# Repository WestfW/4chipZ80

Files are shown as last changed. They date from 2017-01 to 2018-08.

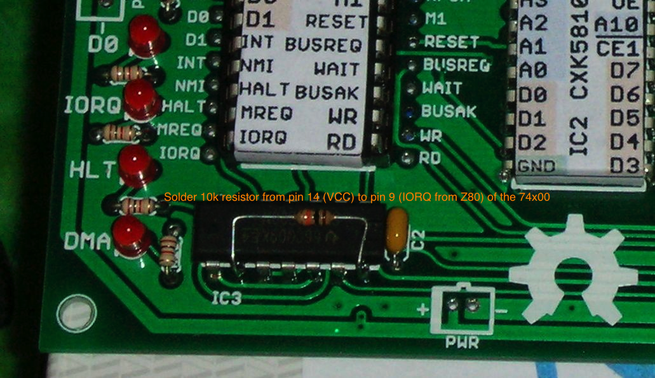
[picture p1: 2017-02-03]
Gerbers-V1bad/Fix-2-IORQ-PullUp.jpg

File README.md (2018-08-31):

# 4chipZ80
Z80 system using ATmega as IO/boot controller.  4 chips total.
---
This is a minimalist Z80 system based on a breadboard design by "Just4Fun" at hackaday.io:
https://hackaday.io/project/19000

My main contribution so far is the creation of a PCB, for a more permenant construction than the original breadboard.
This involved converting the printed schematic to an EAGLE version, as well as laying out the PCB. 

This project has won an **"Anything Goes" HackaDay prize** (for Just4Fun), and at this point has been built by a relatively impressive number of people in a rather impressive variety of different ways (not all of them using this PCB.)

The initial V1 PCB was sent for fabrication at PCBWAY.COM on 20170111.  It's been received, reviewed, and built (fully built as of 20170202), and it works, but it has some bugs:

 1. Short of I2C line to Ground plain.
 2. Missing pullup (IORQ) and pulldown (RESET) resistors.
 3. Rx/Tx swapped on serial connection.
 
Fixing these manually results in a working board.  It's not clear that the pull-resistors are needed.

There are now several versions of the EAGLE Schematic/PCB design posted here:

 1. Gerbers-v1bad.Z80-4chip-PCBWAY-BAD.\* - the design as sent to PCBWAY, complete with errors (except that the errors are "marked.")
With hand-done re-work, this design is known to work.  See the notes in the "To-Do" layer of the board, and the assorted "fix\*" files in that directory.
 1. Z80-4chip-v2.1.\* is the "corrected" design.  It has the fixes for the known bugs.  It also features a clarified (multi-sheet) schematic, *BUT* I have not personally fabbed or tested it, but several people on Hackaday.io have built V2 boards and say that they work.
 2. Z80-4chip-v3.\* Adds sockets for I2C EEPROM "Floppy Disks" that should permit use of CP/M and perhaps other Operating Systems.  Just4Fun has implemented the CP/M and QP/M BIOS and etc.  This has also not yet been fabbed or tested (but I have a volunteer!)  (Also Gerbers-V3/\* has pre-made geber files.)

I don't know if I'll be sending the "new" design(s) to actually be built.  A guy can only use so many Z80 boards, and I'm not up for being "in business."  I'll try to keep this update if other people use the design successfully.

Potential users may want to note that the original developer of the 4-chip Z80 system (Just4Fun) has published a new and improved version of the design that includes a PCB, at https://hackaday.io/project/159973

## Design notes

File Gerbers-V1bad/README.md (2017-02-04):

# Gerbers-V1bad

This has Gerber and Design files for the fabbed board that has know bugs
(but can be made to work.  See photos and .BRD file for detailed (?)
descriptions of the errors (look on the TODO and HISTORY layers.)

 1. SCL shorted to bottom-side ground trace.
 2. RX and TX on FTDI connector swapped.
 3. Missing pullup on IORQ  (may not be required)
 4. Missing pulldown on RESET  (may not be required)

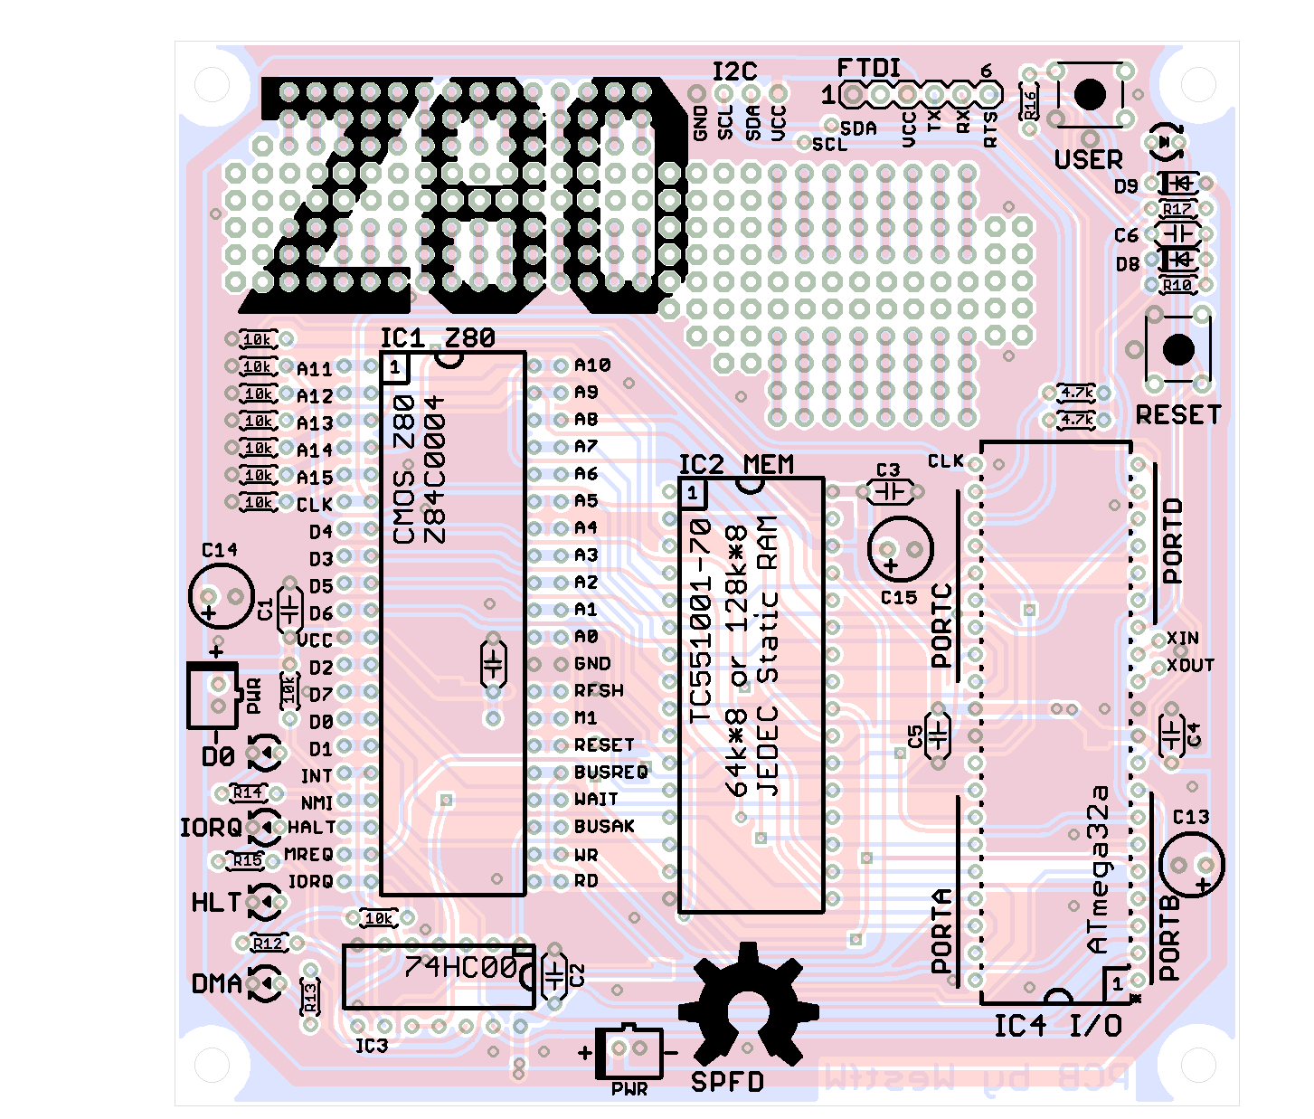
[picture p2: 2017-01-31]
z80.png

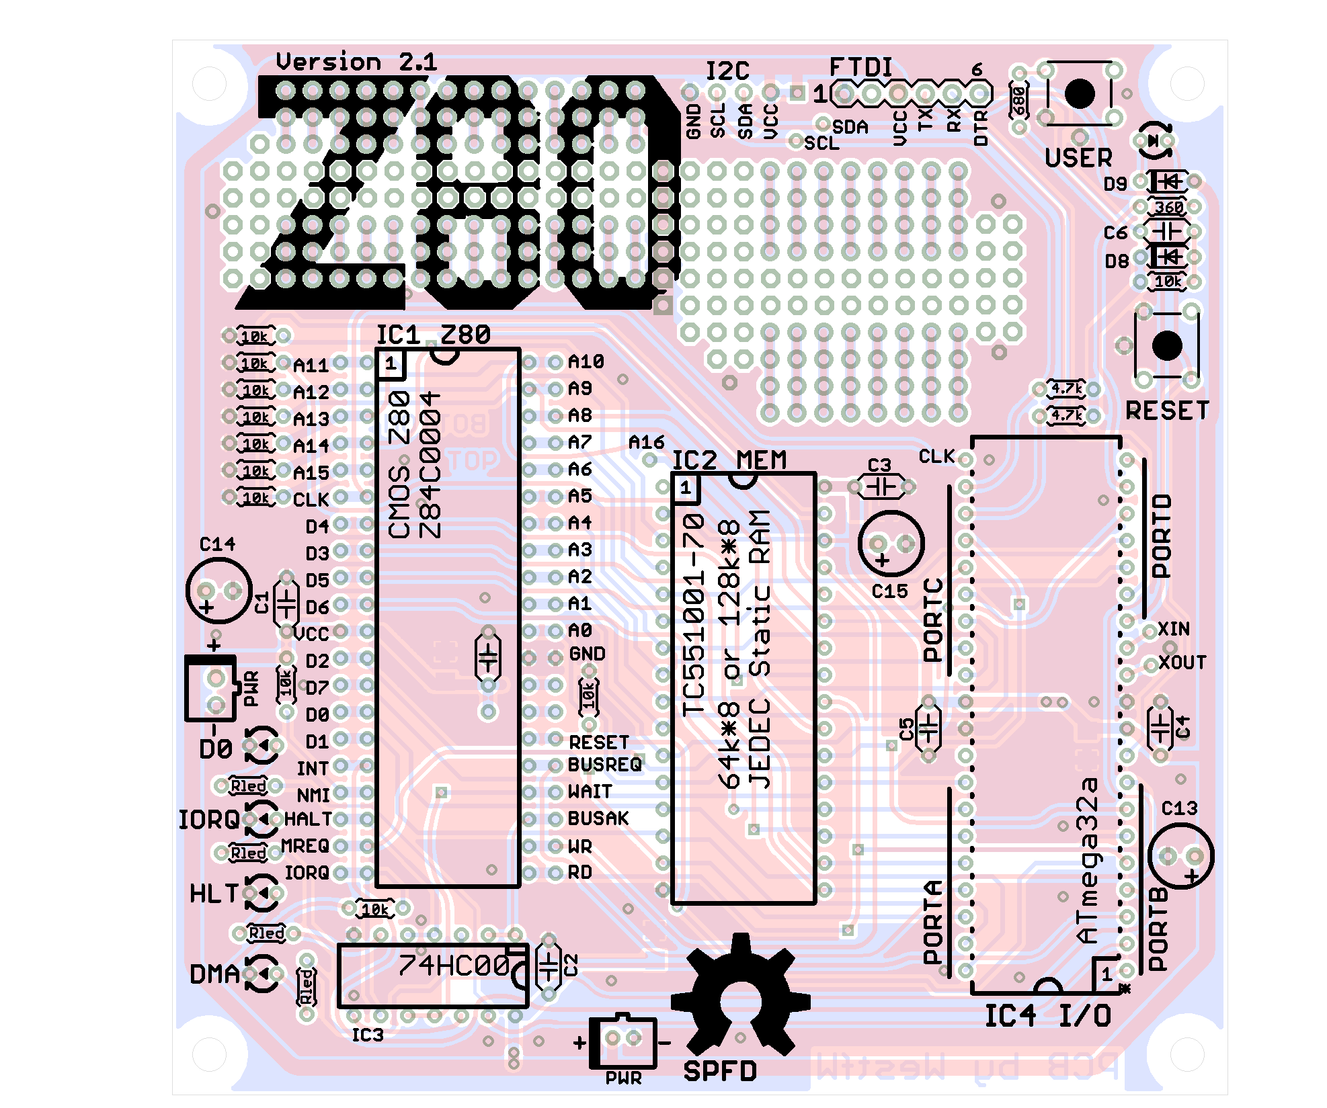
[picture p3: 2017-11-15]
Z80-4chip-v2.1.png

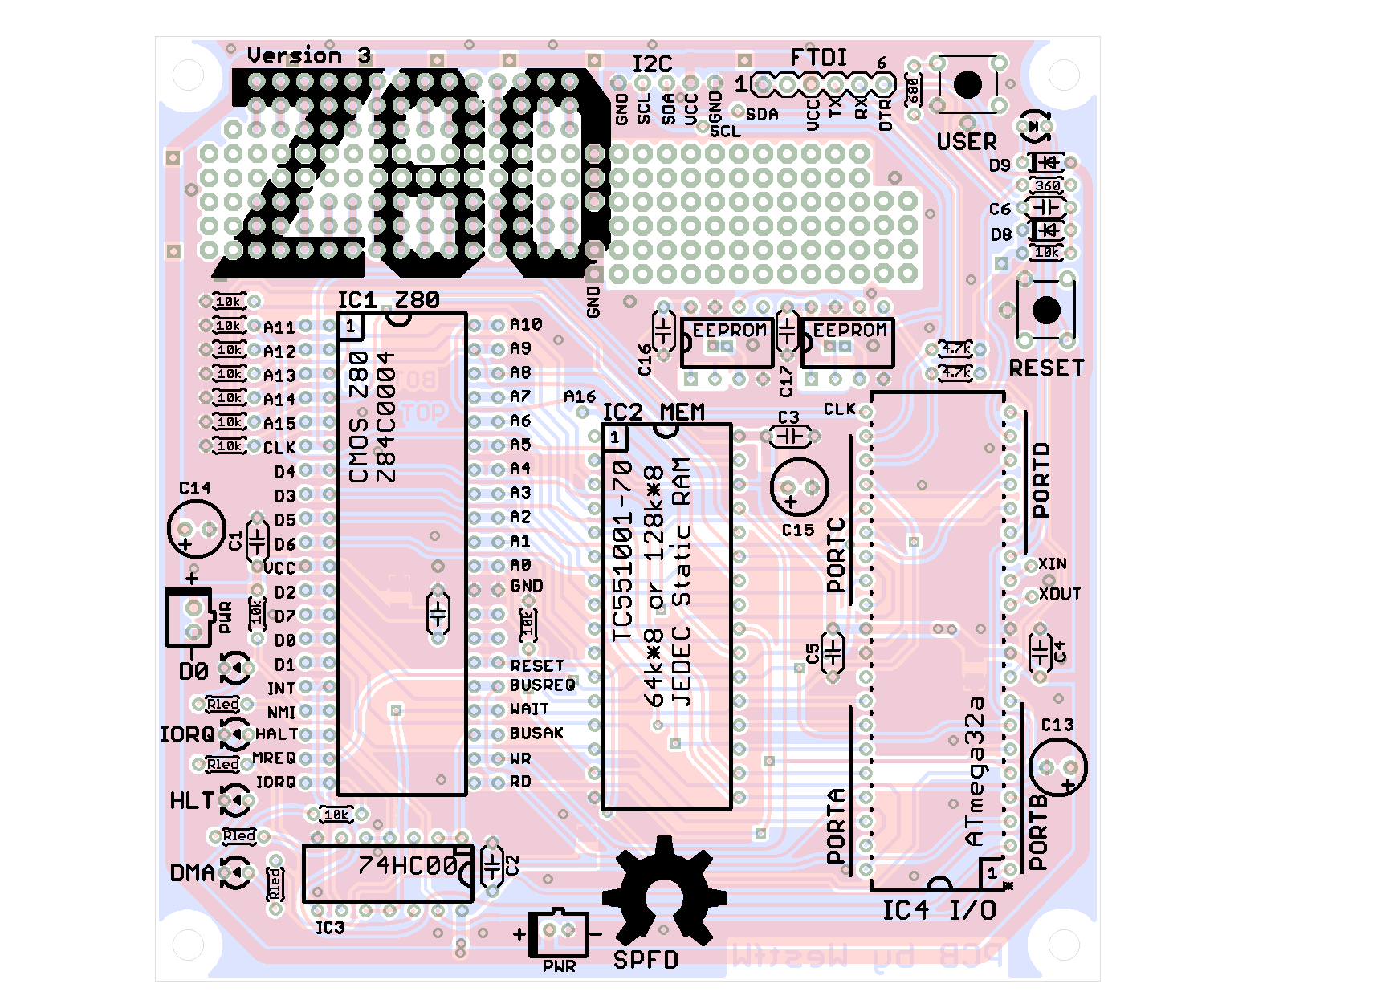
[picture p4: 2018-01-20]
Z80-4chip-v3.png

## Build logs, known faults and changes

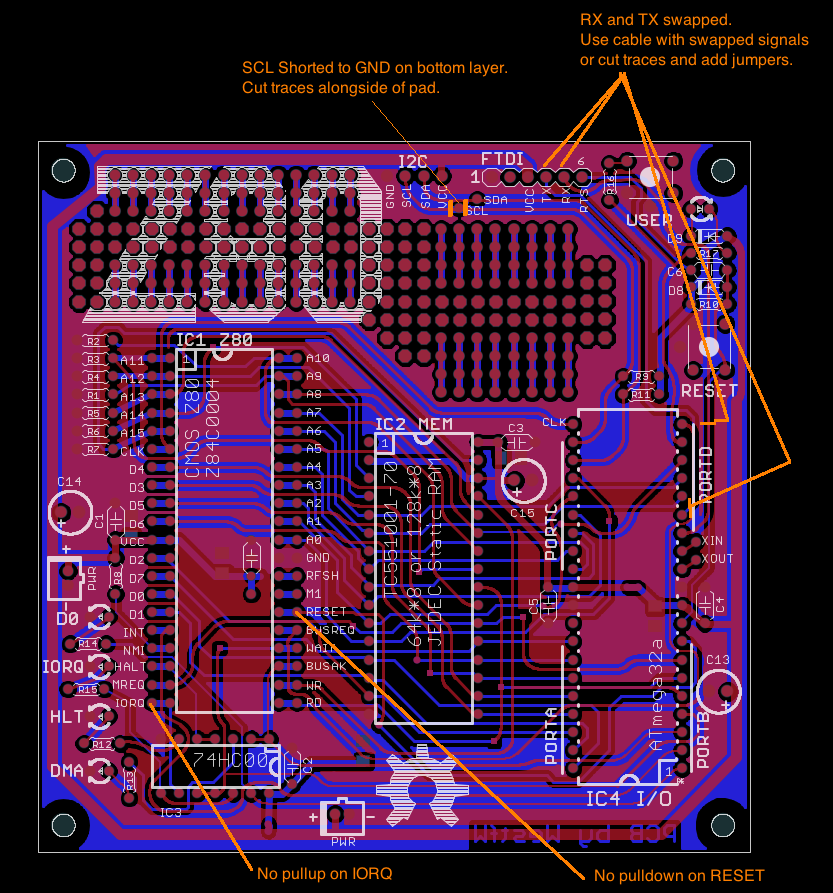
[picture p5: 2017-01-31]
Gerbers-V1bad/Fixes.png

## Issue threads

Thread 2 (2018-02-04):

V3 PCB has 2nd EEPROM at address x2 instead of x1.

WestfW, 2018-02-04:
The address pins of the EEPROMs are wired such that they appear at I2C address 0x50 and 0x52, instead of 0x50 and 051 as shown in the original schematics.  This is easy enough to fix in the ATmega code that handles "disks":

`#define   EXT_EEPROM1   0x52  // I2C EEPROM 1 address (128kB))`

Or, the address pins can be rewired on the bottom layer of the board by cutting a trace and adding a jumper (the PCB layout is designed to allow this to be done "relatively easily.")

Foschia, 2018-03-06:
Hi
It is one of my solution to change the i2c EEPROM address.
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

WestfW, 2018-03-06:
That's pretty!  The extra unmasked vias (VCC and GND) by the EEPROMs were actually put there to allow them to be "easily" re-addressed, so I anticipated something like:
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
But there's a certain elegance to the nice, straight, fixed-length jumpers...

Do you think it was helpful to have the "cut" spots of the traces unmasked?  My theory was that having them uncovered would be "nice", but I see they got solder-plated instead of masked, so I'm not sure that worked out the way I had in mind.  (at least, not for reasonably transparent soldermasks.)

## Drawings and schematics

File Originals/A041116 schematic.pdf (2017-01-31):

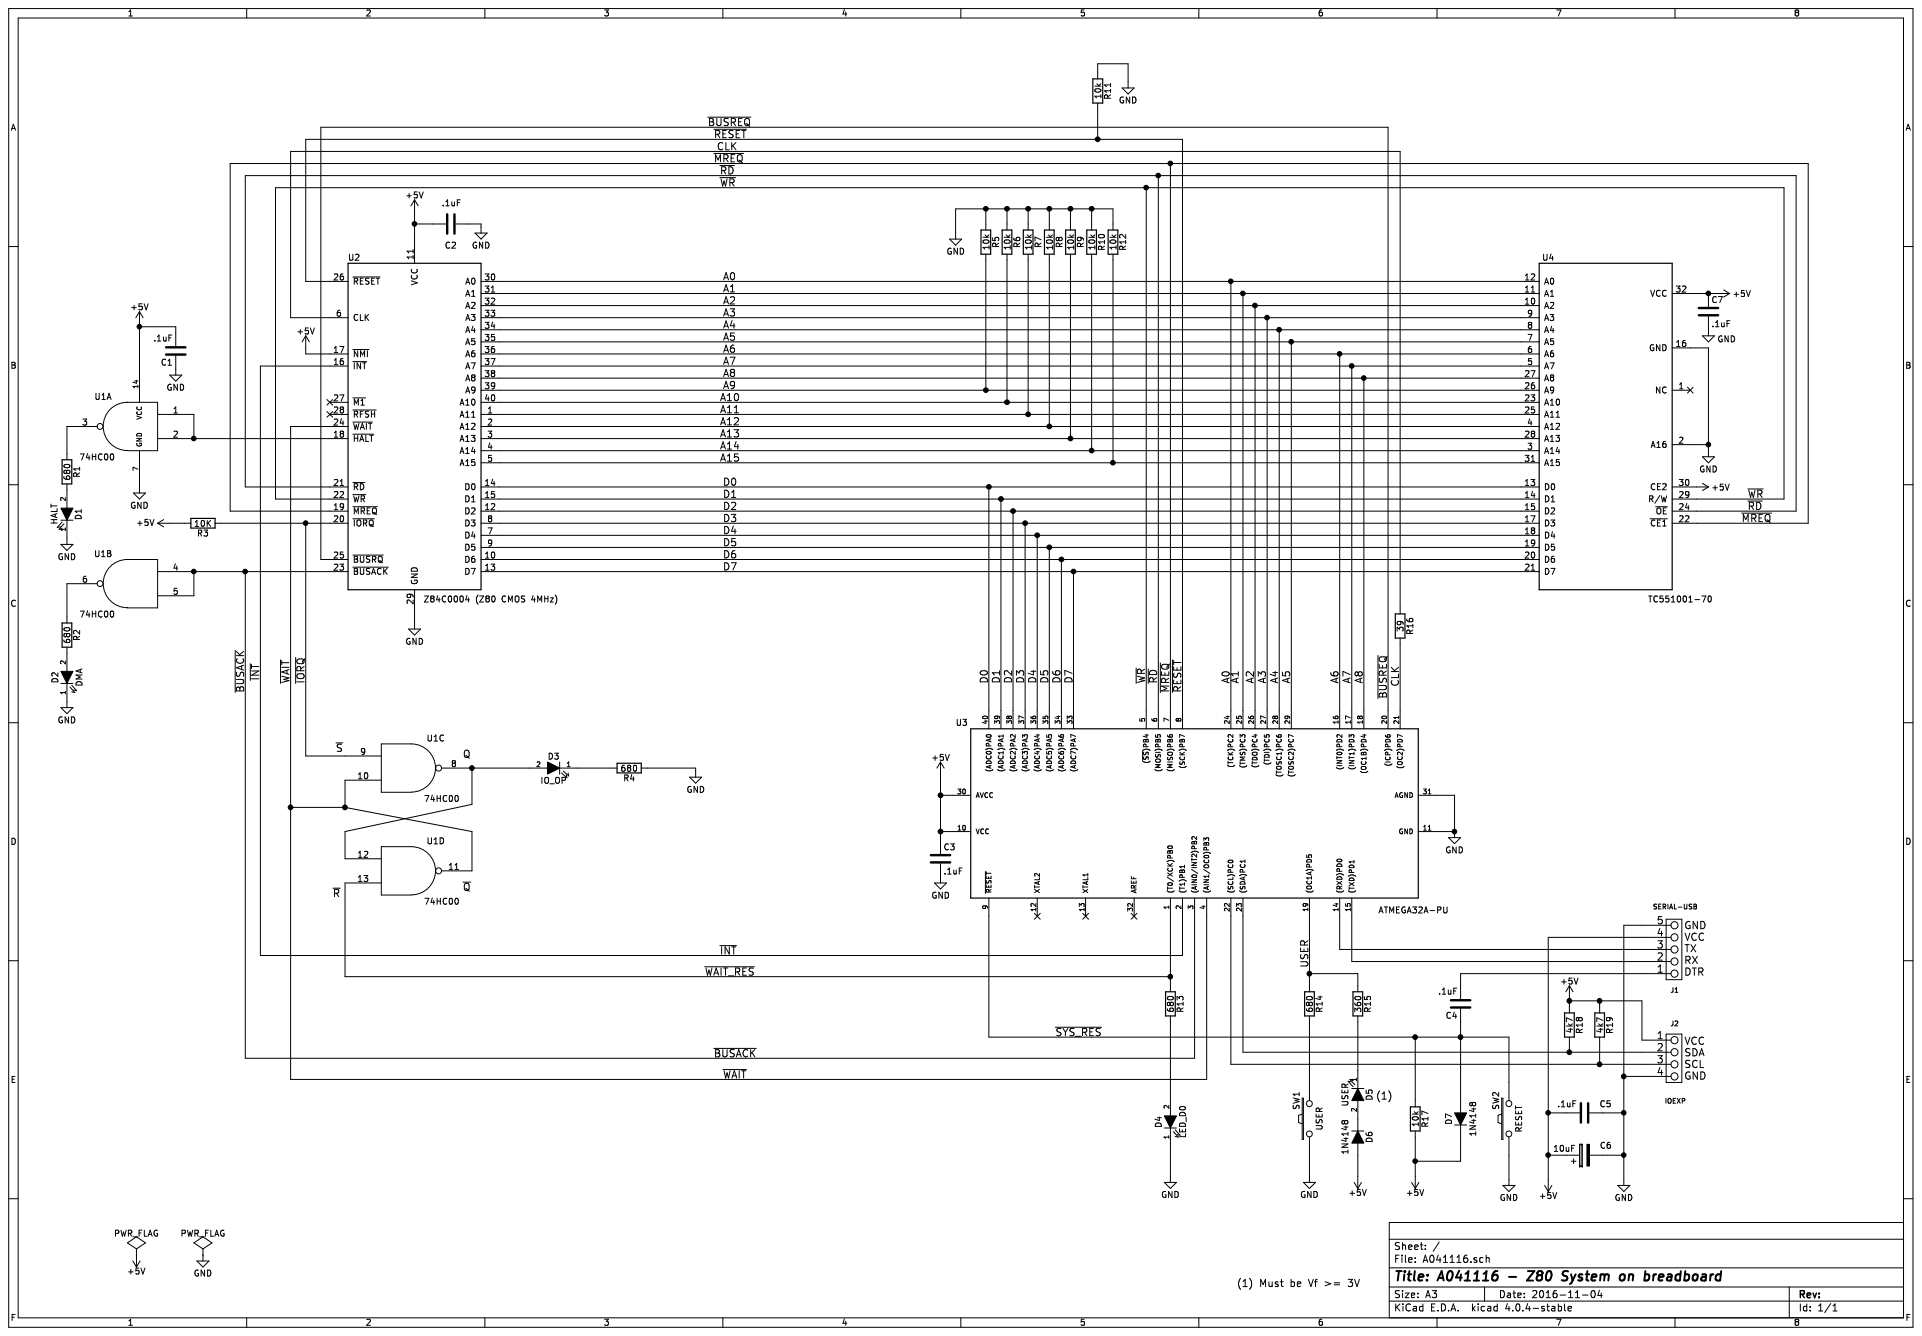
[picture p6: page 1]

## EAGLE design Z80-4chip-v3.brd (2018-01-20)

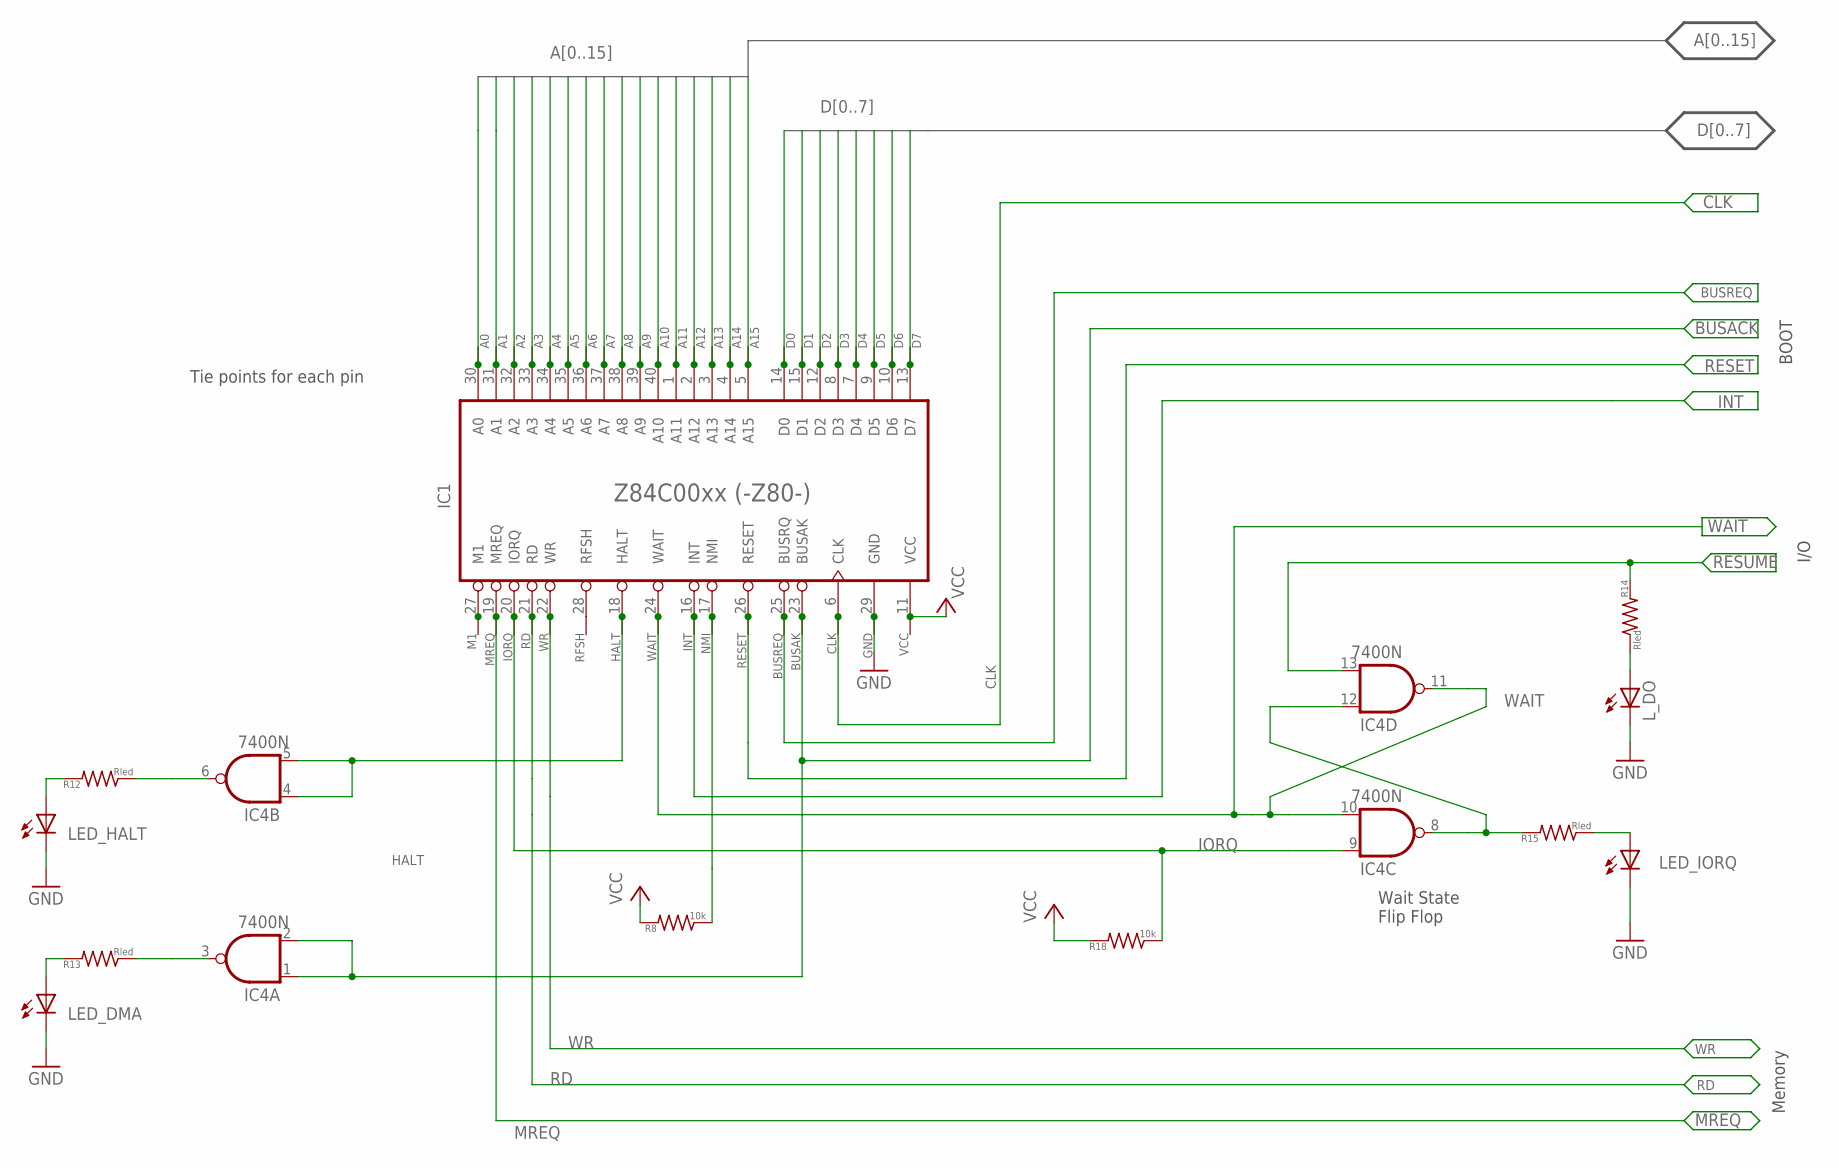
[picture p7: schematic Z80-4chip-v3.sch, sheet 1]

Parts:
A0, A1, A2, A3, A4, A5, A6, A7, A8, A9, A10, A11, A12, A13, A14, A15: WIRE-VIA8; VIA8
BUSAK: WIRE-VIA8; VIA8
BUSREQ: WIRE-VIA8; VIA8
CLK: WIRE-VIA8; VIA8
D0, D1, D2, D3, D4, D5, D6, D7: WIRE-VIA8; VIA8
GND: WIRE-VIA8; VIA8
HALT: WIRE-VIA8; VIA8
IC1: Z84C00xx (-Z80-); DIL40
IC4: 7400N; DIL14
INT: WIRE-VIA8; VIA8
IORQ: WIRE-VIA8; VIA8
LED_DMA: LED3MM
LED_HALT: LED3MM
LED_IORQ: LED3MM
L_DO: LED3MM
M1: WIRE-VIA8; VIA8
MREQ: WIRE-VIA8; VIA8
NMI: WIRE-VIA8; VIA8
R8, R18: 10k; 0204/5
R12, R13, R14, R15: Rled; 0204/5
RD: WIRE-VIA8; VIA8
RESET: WIRE-VIA8; VIA8
RFSH: WIRE-VIA8; VIA8
VCC: WIRE-VIA8; VIA8
WAIT: WIRE-VIA8; VIA8
WR: WIRE-VIA8; VIA8

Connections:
A0: A0.P$1, IC1.30 (A0); also elsewhere on the board
A1: A1.P$1, IC1.31 (A1); also elsewhere on the board
A2: A2.P$1, IC1.32 (A2); also elsewhere on the board
A3: A3.P$1, IC1.33 (A3); also elsewhere on the board
A4: A4.P$1, IC1.34 (A4); also elsewhere on the board
A5: A5.P$1, IC1.35 (A5); also elsewhere on the board
A6: A6.P$1, IC1.36 (A6); also elsewhere on the board
A7: A7.P$1, IC1.37 (A7); also elsewhere on the board
A8: A8.P$1, IC1.38 (A8); also elsewhere on the board
A9: A9.P$1, IC1.39 (A9); also elsewhere on the board
A10: A10.P$1, IC1.40 (A10); also elsewhere on the board
A11: A11.P$1, IC1.1 (A11); also elsewhere on the board
A12: A12.P$1, IC1.2 (A12); also elsewhere on the board
A13: A13.P$1, IC1.3 (A13); also elsewhere on the board
A14: A14.P$1, IC1.4 (A14); also elsewhere on the board
A15: A15.P$1, IC1.5 (A15); also elsewhere on the board
BUSACK: BUSAK.P$1, IC1.23 (BUSAK), IC4.1 (I0), IC4.2 (I1); also elsewhere on the board
BUSREQ: BUSREQ.P$1, IC1.25 (BUSRQ); also elsewhere on the board
CLK: CLK.P$1, IC1.6 (CLK); also elsewhere on the board
D0: D0.P$1, IC1.14 (D0); also elsewhere on the board
D1: D1.P$1, IC1.15 (D1); also elsewhere on the board
D2: D2.P$1, IC1.12 (D2); also elsewhere on the board
D3: D3.P$1, IC1.8 (D3); also elsewhere on the board
D4: D4.P$1, IC1.7 (D4); also elsewhere on the board
D5: D5.P$1, IC1.9 (D5); also elsewhere on the board
D6: D6.P$1, IC1.10 (D6); also elsewhere on the board
D7: D7.P$1, IC1.13 (D7); also elsewhere on the board
GND: GND.P$1, IC1.29 (GND), LED_DMA.K (C), LED_HALT.K (C), LED_IORQ.K (C), L_DO.K (C); also elsewhere on the board
HALT: HALT.P$1, IC1.18 (HALT), IC4.4 (I0), IC4.5 (I1)
INT: IC1.16 (INT), INT.P$1; also elsewhere on the board
IORQ: IC1.20 (IORQ), IC4.9 (I0), IORQ.P$1, R18.1
MREQ: IC1.19 (MREQ), MREQ.P$1; also elsewhere on the board
unnamed: IC1.27 (M1), M1.P$1
unnamed: IC4.6 (O), R12.1
unnamed: IC4.3 (O), R13.1
unnamed: LED_HALT.A, R12.2
unnamed: LED_DMA.A, R13.2
unnamed: L_DO.A, R14.1
unnamed: LED_IORQ.A, R15.1
unnamed: IC1.28 (RFSH), RFSH.P$1
unnamed: IC4.8 (O), IC4.12 (I0), R15.2
NMI: IC1.17 (NMI), NMI.P$1, R8.1
RD: IC1.21 (RD), RD.P$1; also elsewhere on the board
RESET: IC1.26 (RESET), RESET.P$1; also elsewhere on the board
RESUME: IC4.13 (I1), R14.2; also elsewhere on the board
VCC: IC1.11 (VCC), R8.2, R18.2, VCC.P$1; also elsewhere on the board
WAIT: IC1.24 (WAIT), IC4.10 (I1), IC4.11 (O), WAIT.P$1; also elsewhere on the board
WR: IC1.22 (WR), WR.P$1; also elsewhere on the board

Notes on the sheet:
Tie points for each pin
Memory
I/O
BOOT
Wait State Flip Flop

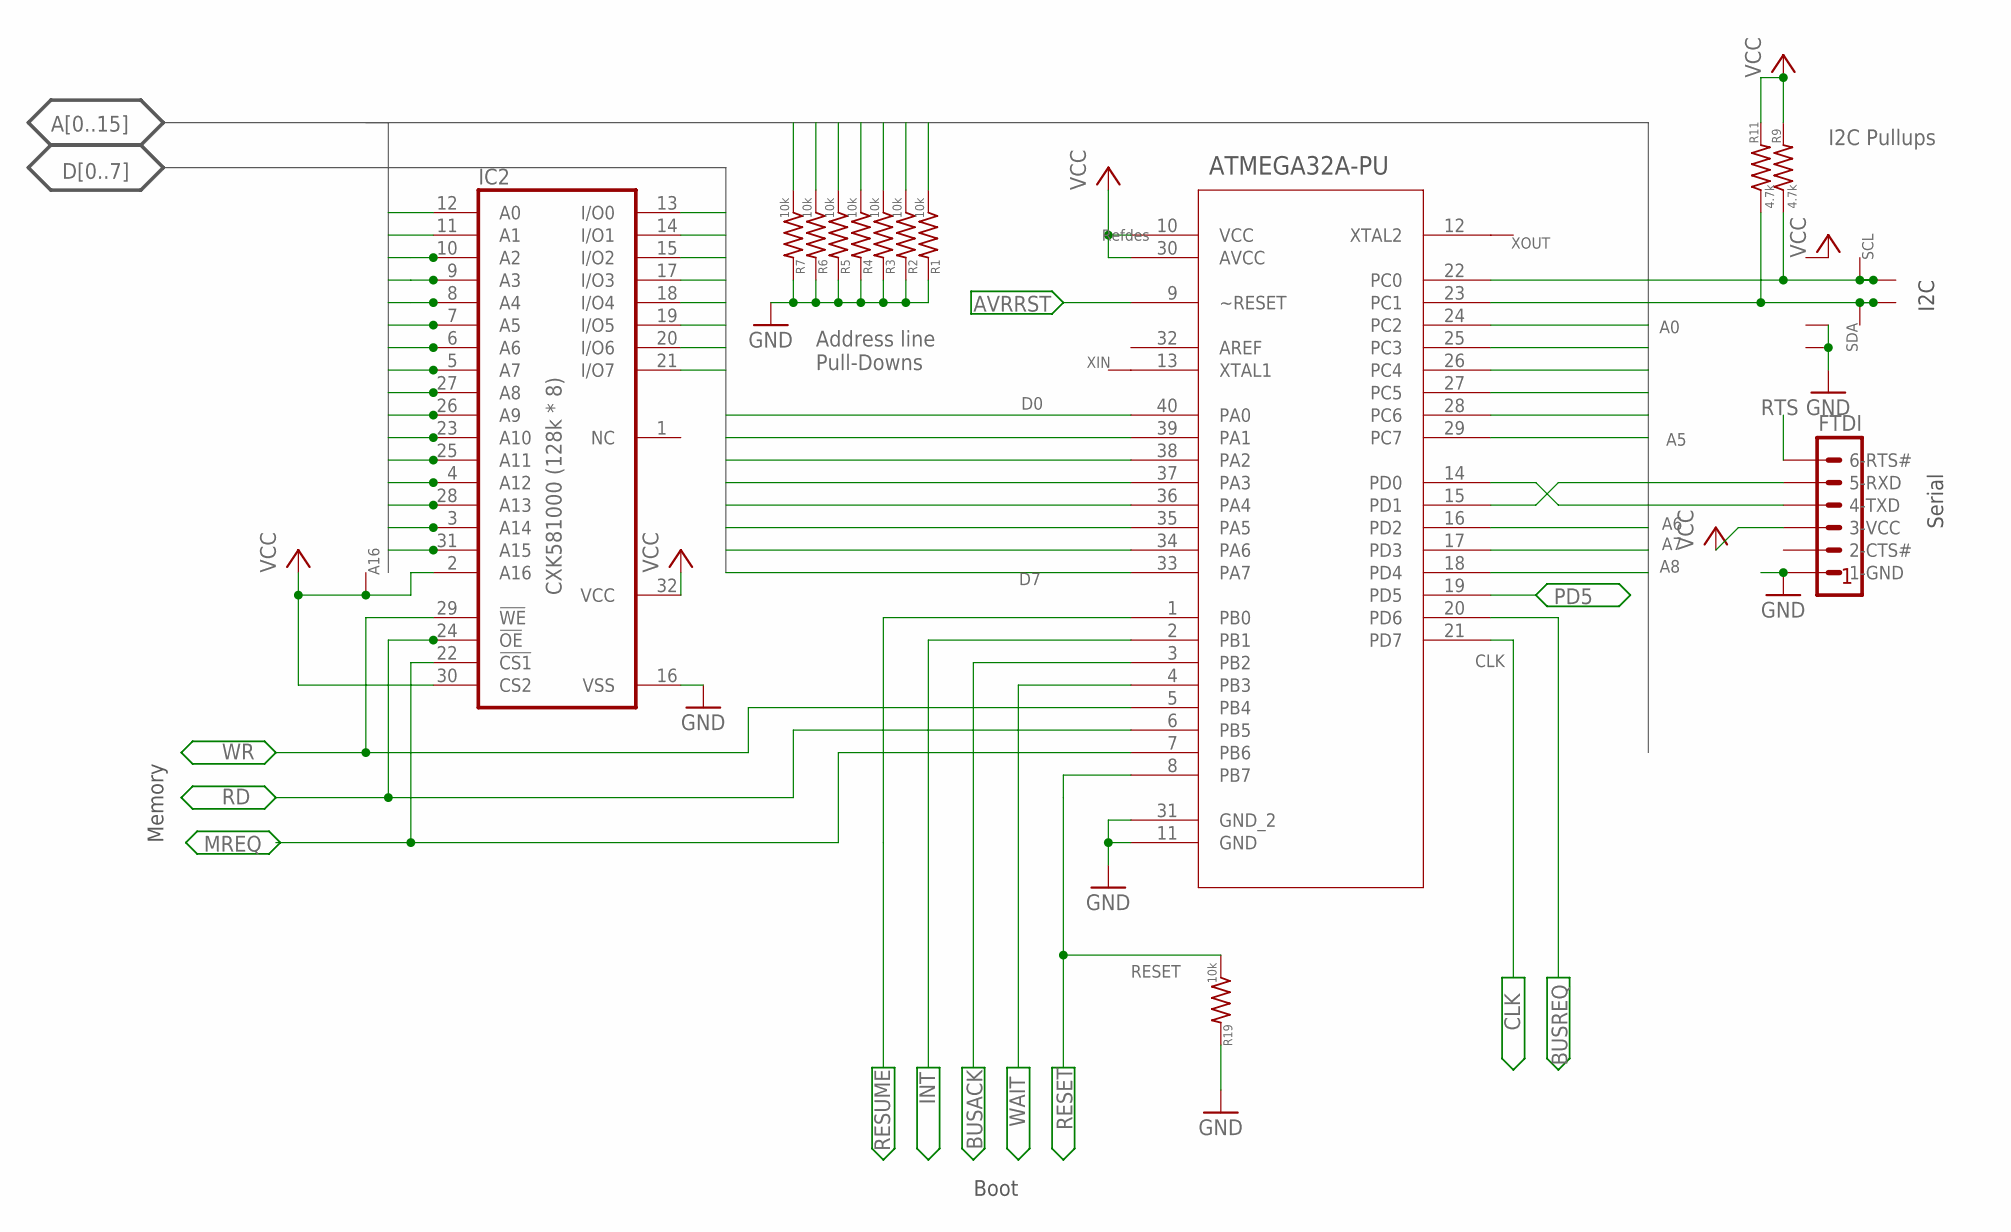
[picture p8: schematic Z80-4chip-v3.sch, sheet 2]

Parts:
A16: WIRE-VIA8; VIA8
FTDI: FTDI-TTL232R; MA06-1
I2CG, I2CGND, I2CV: WIRE-R10; VIA10
IC2: CXK581000 (128k * 8); DIL32
R1, R2, R3, R4, R5, R6, R7, R19: 10k; 0204/5
R9, R11: 4.7k; 0204/5
SCL: WIRE-R10; VIA10
SDA: WIRE-R10; VIA10
U1: ATMEGA32A-PU; DIP254P1524X482-40
W1, W2: WIRE-VIA8; VIA8
XIN: WIRE-VIA8; VIA8
XOUT: WIRE-VIA8; VIA8

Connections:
A0: IC2.12 (A0), U1.24 (PC2); also elsewhere on the board
A1: IC2.11 (A1), U1.25 (PC3); also elsewhere on the board
A2: IC2.10 (A2), U1.26 (PC4); also elsewhere on the board
A3: IC2.9 (A3), U1.27 (PC5); also elsewhere on the board
A4: IC2.8 (A4), U1.28 (PC6); also elsewhere on the board
A5: IC2.7 (A5), U1.29 (PC7); also elsewhere on the board
A6: IC2.6 (A6), U1.16 (PD2); also elsewhere on the board
A7: IC2.5 (A7), U1.17 (PD3); also elsewhere on the board
A8: IC2.27 (A8), U1.18 (PD4); also elsewhere on the board
A9: IC2.26 (A9), R1.1; also elsewhere on the board
A10: IC2.23 (A10), R2.1; also elsewhere on the board
A11: IC2.25 (A11), R3.1; also elsewhere on the board
A12: IC2.4 (A12), R4.1; also elsewhere on the board
A13: IC2.28 (A13), R5.1; also elsewhere on the board
A14: IC2.3 (A14), R6.1; also elsewhere on the board
A15: IC2.31 (A15), R7.1; also elsewhere on the board
AVRRST: U1.9 (~RESET); also elsewhere on the board
BUSACK: U1.3 (PB2); also elsewhere on the board
BUSREQ: U1.20 (PD6); also elsewhere on the board
CLK: U1.21 (PD7); also elsewhere on the board
D0: IC2.13 (I/O0), U1.40 (PA0); also elsewhere on the board
D1: IC2.14 (I/O1), U1.39 (PA1); also elsewhere on the board
D2: IC2.15 (I/O2), U1.38 (PA2); also elsewhere on the board
D3: IC2.17 (I/O3), U1.37 (PA3); also elsewhere on the board
D4: IC2.18 (I/O4), U1.36 (PA4); also elsewhere on the board
D5: IC2.19 (I/O5), U1.35 (PA5); also elsewhere on the board
D6: IC2.20 (I/O6), U1.34 (PA6); also elsewhere on the board
D7: IC2.21 (I/O7), U1.33 (PA7); also elsewhere on the board
GND: FTDI.1 (1-GND), I2CG.P$1, I2CGND.P$1, IC2.16 (VSS), R1.2, R2.2, R3.2, R4.2, R5.2, R6.2, R7.2, R19.2, U1.11 (GND), U1.31 (GND_2); also elsewhere on the board
INT: U1.2 (PB1); also elsewhere on the board
MREQ: IC2.22 (!CS1), U1.7 (PB6); also elsewhere on the board
unnamed: FTDI.5 (5-RXD), U1.15 (PD1)
unnamed: FTDI.4 (4-TXD), U1.14 (PD0)
unnamed: U1.13 (XTAL1), XIN.P$1
unnamed: U1.12 (XTAL2), XOUT.P$1
PD5: U1.19 (PD5); also elsewhere on the board
RD: IC2.24 (!OE), U1.6 (PB5); also elsewhere on the board
RESET: R19.1, U1.8 (PB7); also elsewhere on the board
RESUME: U1.1 (PB0); also elsewhere on the board
RTS: FTDI.6 (6-RTS#); also elsewhere on the board
SCL: R9.1, SCL.P$1, U1.22 (PC0), W1.P$1; also elsewhere on the board
SDA: R11.1, SDA.P$1, U1.23 (PC1), W2.P$1; also elsewhere on the board
VCC: A16.P$1, FTDI.3 (3-VCC), I2CV.P$1, IC2.2 (A16), IC2.30 (CS2), IC2.32 (VCC), R9.2, R11.2, U1.10 (VCC), U1.30 (AVCC); also elsewhere on the board
WAIT: U1.4 (PB3); also elsewhere on the board
WR: IC2.29 (!WE), U1.5 (PB4); also elsewhere on the board

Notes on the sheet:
I2C Pullups
Address line Pull-Downs
I2C
Memory
Boot
Serial

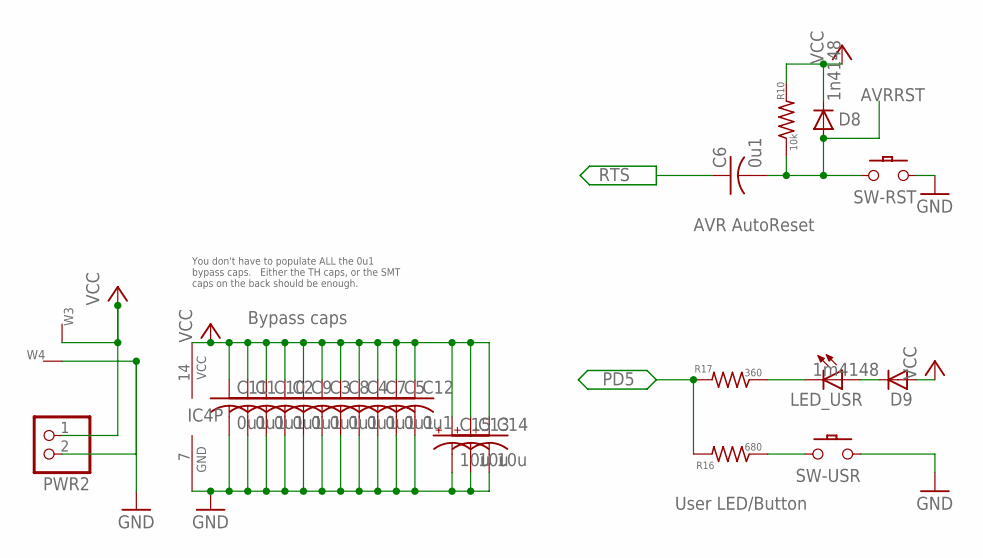
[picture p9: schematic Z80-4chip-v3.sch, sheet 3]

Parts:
C1, C2, C3, C4, C5, C6, C7: 0u1; C050-024X044
C8, C9, C10, C11, C12: 0u1; C1206
C13, C14, C15: 10u; E2,5-6
D8: 1n4148; DO35-5
D9: 1m4148; DO35-5
IC4: 7400N; DIL14
LED_USR: LED3MM
PWR2: JST_2PIN-THM; JST-PH-2-THM
R10: 10k; 0204/5
R16: 680; 0204/5
R17: 360; 0204/5
SW-RST: SW-PB2/; SW-PB
SW-USR: SW-PB2L; SW-PB
W3, W4: WIRE-R10; VIA10

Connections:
AVRRST: C6.2, D8.A, R10.1, SW-RST.3; also elsewhere on the board
GND: C1.2, C2.2, C3.2, C4.2, C5.2, C7.2, C8.2, C9.2, C10.2, C11.2, C12.2, C13.-, C14.-, C15.-, IC4.7 (GND), PWR2.2 (1), SW-RST.2, SW-RST.5 (GND), SW-USR.2, SW-USR.5 (GND), W4.P$1; also elsewhere on the board
unnamed: LED_USR.K (C), R17.1
unnamed: D9.C, LED_USR.A
unnamed: R16.1, SW-USR.4
PD5: R16.2, R17.2; also elsewhere on the board
RTS: C6.1; also elsewhere on the board
VCC: C1.1, C2.1, C3.1, C4.1, C5.1, C7.1, C8.1, C9.1, C10.1, C11.1, C12.1, C13.+, C14.+, C15.+, D8.C, D9.A, IC4.14 (VCC), PWR2.1 (2), R10.2, W3.P$1; also elsewhere on the board

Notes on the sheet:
Bypass caps
You don't have to populate ALL the 0u1 bypass caps. Either the TH caps, or the SMT caps on the back should be enough.
AVR AutoReset
User LED/Button

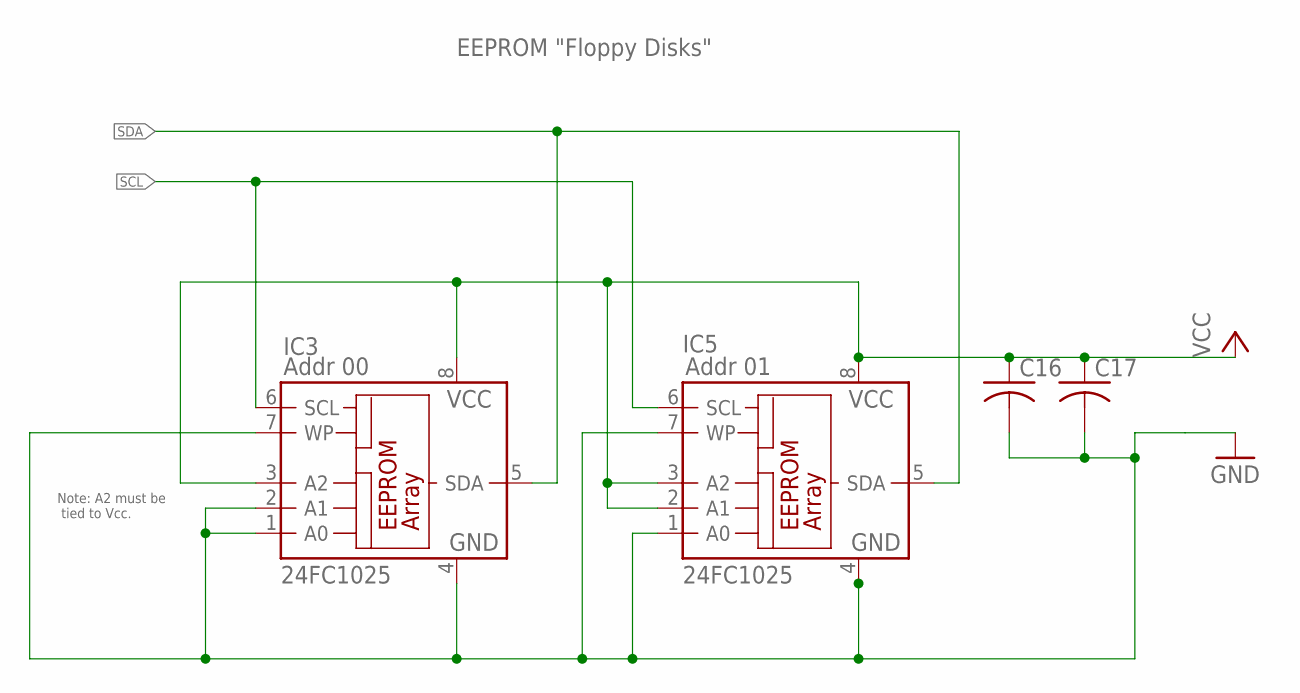
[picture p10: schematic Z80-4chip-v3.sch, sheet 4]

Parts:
C16, C17: C-US-5MM; C050-024X044
IC3, IC5: 24FC1025; DIL8

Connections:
GND: C16.2, C17.2, IC3.1 (A0), IC3.2 (A1), IC3.4 (GND), IC3.7 (WP), IC5.1 (A0), IC5.4 (GND), IC5.7 (WP); also elsewhere on the board
SCL: IC3.6 (SCL), IC5.6 (SCL); also elsewhere on the board
SDA: IC3.5 (SDA), IC5.5 (SDA); also elsewhere on the board
VCC: C16.1, C17.1, IC3.3 (A2), IC3.8 (VCC), IC5.2 (A1), IC5.3 (A2), IC5.8 (VCC); also elsewhere on the board

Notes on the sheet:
Addr 00
Addr 01
EEPROM "Floppy Disks"
Note: A2 must be tied to Vcc.

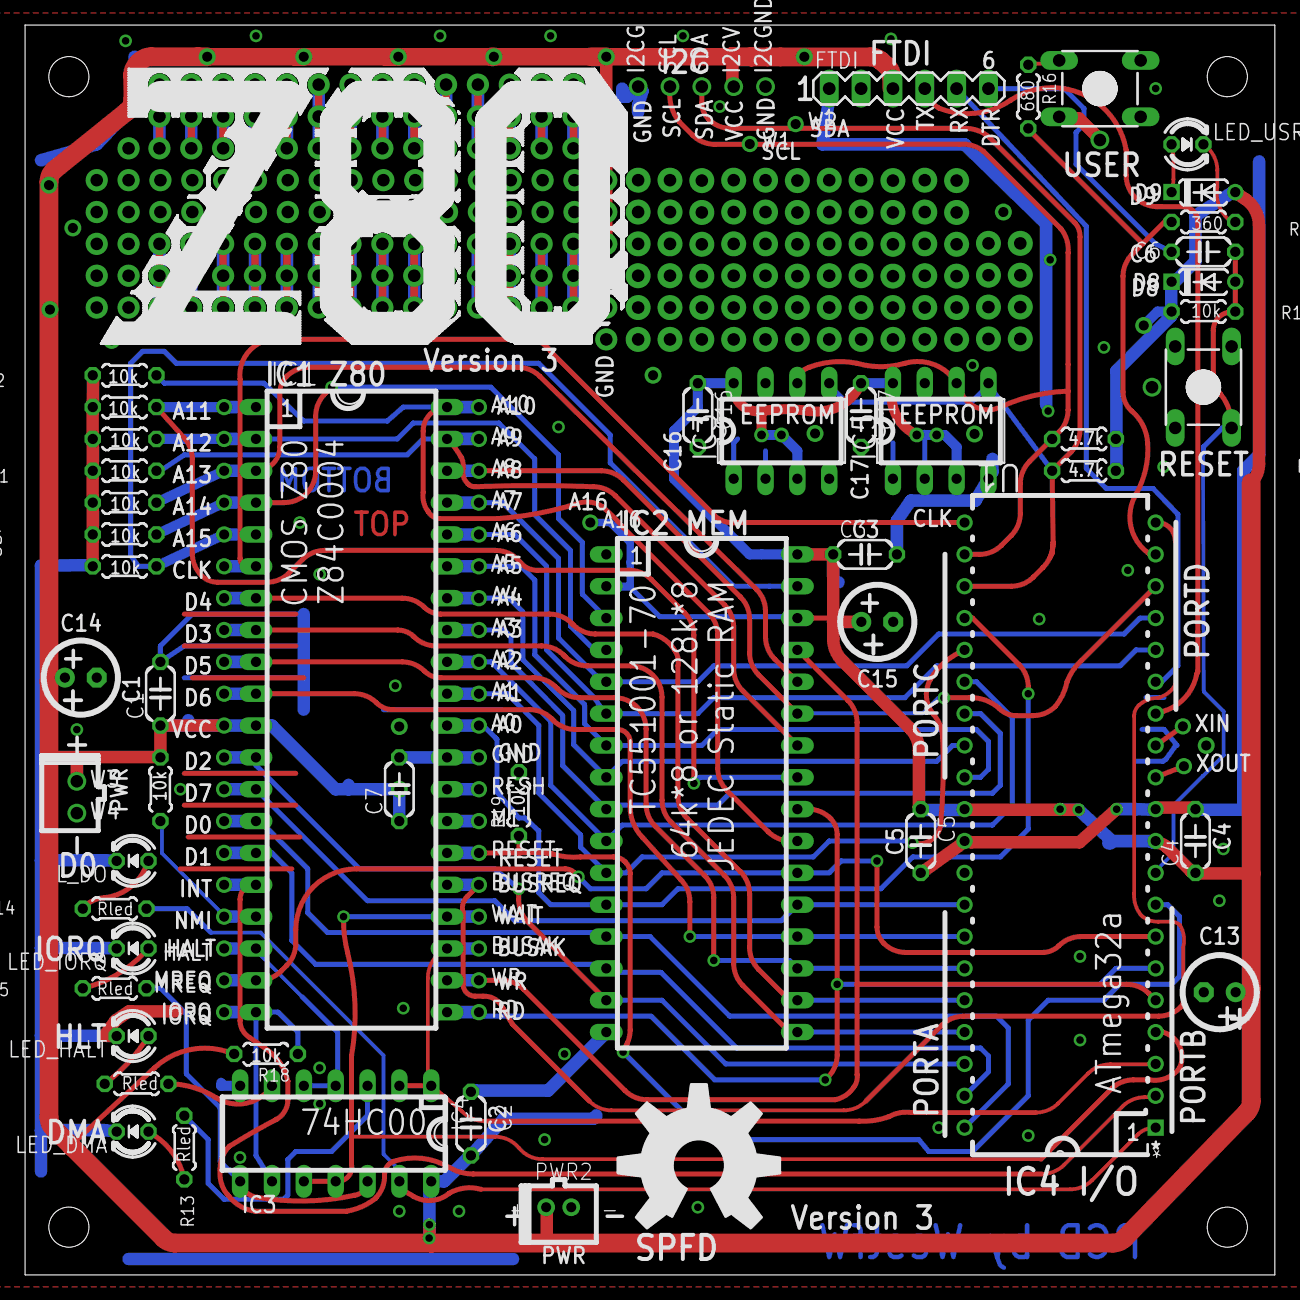
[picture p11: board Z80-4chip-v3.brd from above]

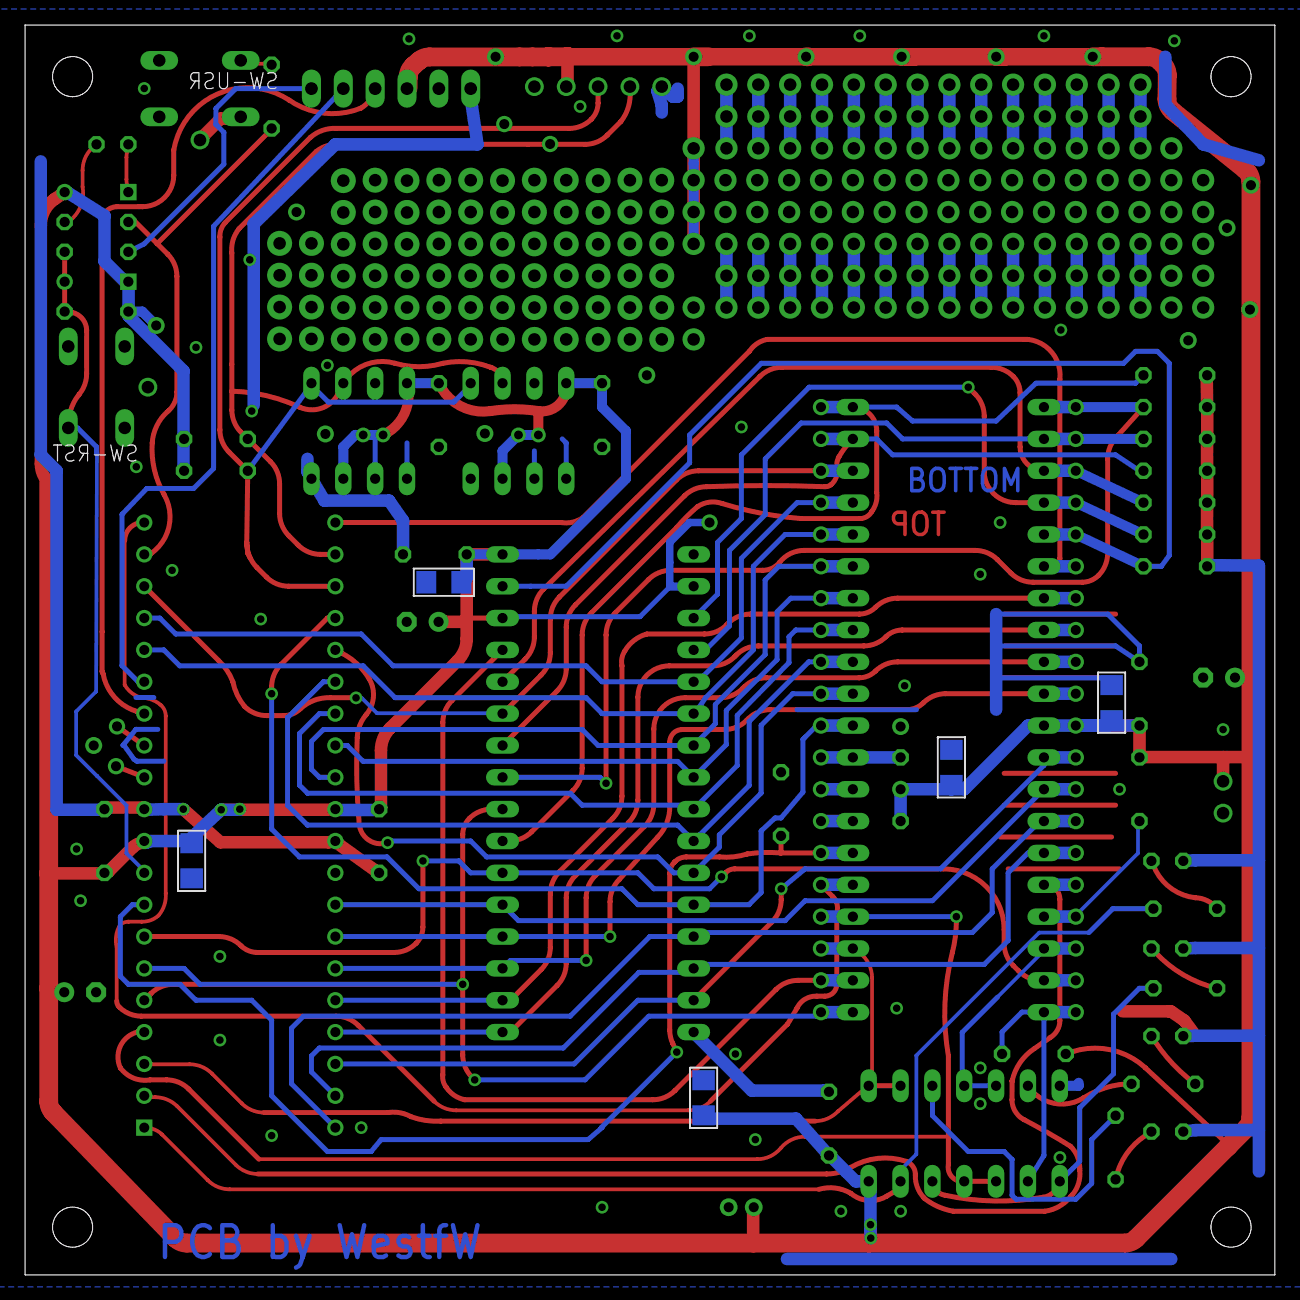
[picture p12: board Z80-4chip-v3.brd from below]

Board: 2 copper layers, 99.7 x 99.7 mm, 105 parts (5 on the bottom side), 60 nets.

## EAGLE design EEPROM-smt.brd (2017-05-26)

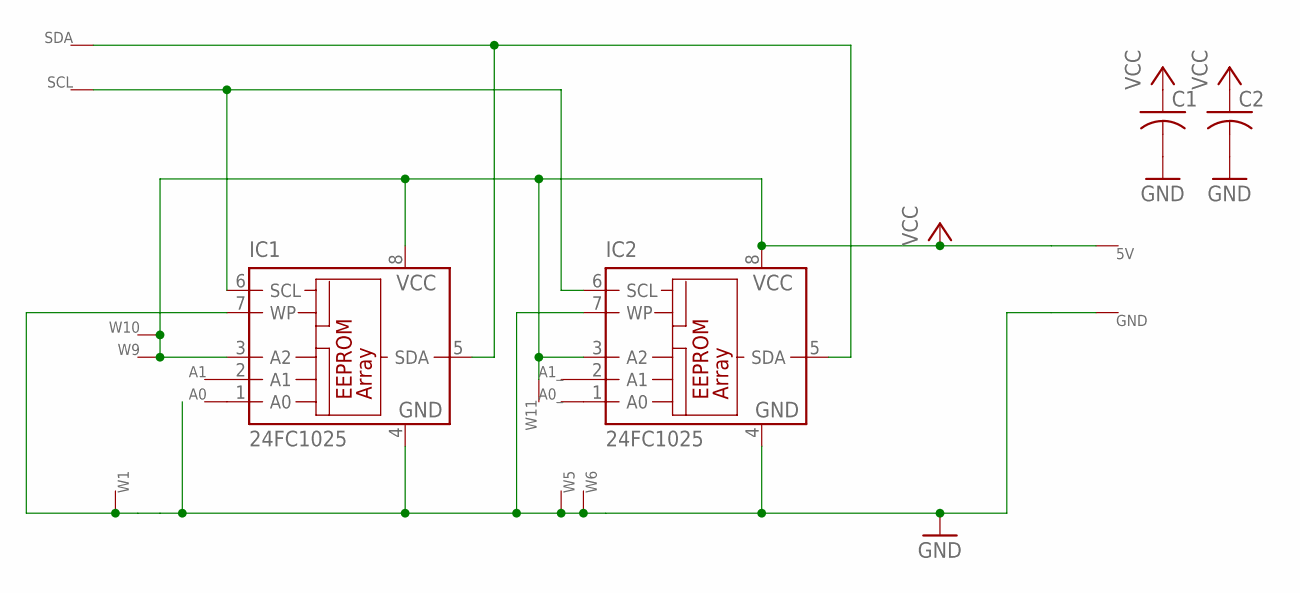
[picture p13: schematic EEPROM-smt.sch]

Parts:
5V: WIRE-VIA8; VIA8
A0, A0_, A1, A1_: WIRE-R6; VIA6
C1, C2: C-USC0805; C0805
GND: WIRE-VIA8; VIA8
IC1, IC2: 24FC1025; SO-08
SCL: WIRE-VIA8; VIA8
SDA: WIRE-VIA8; VIA8
W1, W5, W6, W9, W10, W11: WIRE-VIA8; VIA8

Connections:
GND: C1.2, C2.2, GND.P$1, IC1.4 (GND), IC1.7 (WP), IC2.4 (GND), IC2.7 (WP), W1.P$1, W5.P$1, W6.P$1
unnamed: A1.P$1, IC1.2 (A1)
unnamed: A0.P$1, IC1.1 (A0)
unnamed: IC1.6 (SCL), IC2.6 (SCL), SCL.P$1
unnamed: IC1.5 (SDA), IC2.5 (SDA), SDA.P$1
unnamed: A1_.P$1, IC2.2 (A1)
unnamed: A0_.P$1, IC2.1 (A0)
VCC: 5V.P$1, C1.1, C2.1, IC1.3 (A2), IC1.8 (VCC), IC2.3 (A2), IC2.8 (VCC), W9.P$1, W10.P$1, W11.P$1

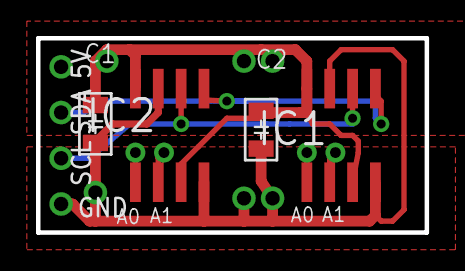
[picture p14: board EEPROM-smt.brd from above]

Board: 2 copper layers, 21.6 x 10.8 mm, 18 parts (0 on the bottom side), 8 nets.

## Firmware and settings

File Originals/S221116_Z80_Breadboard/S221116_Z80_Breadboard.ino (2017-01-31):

/* ------------------------------------------------------------------------------

S221116 - HW ref: A041116

IOS - I/O Subsystem - for Z80-MBC (Mobile Breadboard Computer)
(Z80 64kB RAM @ 4Mhz)



Notes:

1:  This SW is ONLY for the Atmega32A used as EEPROM and I/O subsystem (8MHz internal oscillator).
    
2:  Tested on ATmega16A/Atmega32A @ Arduino IDE 1.6.5.

3:  Embedded FW: S091116 Loader, S121216 uBIOS + Basic

4:  Utilities: S111216 TASM conversion utility (S111216.c)

--------------------------------------------------------------------------------- */


// ------------------------------------------------------------------------------
//
// Hardware definitions (see A041116 schematic)
//
// ------------------------------------------------------------------------------

#define   D0          24  // PA0 pin 40   Z80 data bus
#define   D1          25  // PA1 pin 39
#define   D2          26  // PA2 pin 38
#define   D3          27  // PA3 pin 37
#define   D4          28  // PA4 pin 36
#define   D5          29  // PA5 pin 35
#define   D6          30  // PA6 pin 34
#define   D7          31  // PA7 pin 33

#define   AD0         18  // PC2 pin 24   Z80 address bus (AD0-AD8 = A0-A8 on A04113 schematic)
#define   AD1         19  // PC3 pin 25
#define   AD2         20  // PC4 pin 26
#define   AD3         21  // PC5 pin 27
#define   AD4         22  // PC6 pin 28
#define   AD5         23  // PC7 pin 29
#define   AD6         10  // PD2 pin 16
#define   AD7         11  // PD3 pin 17
#define   AD8         12  // PD4 pin 18

#define   INT_         1  // PB1 pin 2    Z80 control bus
#define   BUSACK_      2  // PB2 pin 3
#define   WAIT_        3  // PB3 pin 4
#define   WR_          4  // PB4 pin 5
#define   RD_          5  // PB5 pin 6
#define   MREQ_        6  // PB6 pin 7
#define   RESET_       7  // PB7 pin 8
#define   BUSREQ_     14  // PD6 pin 20
#define   CLK         15  // PD7 pin 21

#define   SCL_PC0     16  // PC0 pin 22   IOEXP connector
#define   SDA_PC1     17  // PC1 pin 23

#define   LED_D0       0  // PB0 pin 1    Led LED_0 ON if HIGH
#define   WAIT_RES_    0  // PB0 pin 1    Internal control line
#define   USER        13  // PD5 pin 19   Led USER and key

// ------------------------------------------------------------------------------
//
//  Libraries
//
// ------------------------------------------------------------------------------

#include <avr/pgmspace.h>                 // needed for PROGMEM

// ------------------------------------------------------------------------------
//
//  Constants
//
// ------------------------------------------------------------------------------

const byte  debugLev          = 0;      // Set the level of debug (0 = no debug, 1 = only phase 1 boot, 
                                        // 2 = 1 + phase 2 boot + runtime I/O)
                                        
const word  bootPhase1StrAddr = 0x0000; // Phase 1 payload image starting address
const byte  bootPhase1[] PROGMEM = {    // Phase 1 payload image (S091116 Loader) 
  0xC3, 0x07, 0x00, 0x00, 0x00, 0x00, 0x00, 0x21, 0x15, 0x00, 0x11, 0x00, 0xFC, 0x01, 0x24, 0x00, 
  0xED, 0xB0, 0xC3, 0x00, 0xFC, 0xED, 0x5B, 0x05, 0x00, 0x2A, 0x03, 0x00, 0xDD, 0x2A, 0x03, 0x00, 
  0x0E, 0x02, 0x06, 0x00, 0x7A, 0xB7, 0xCA, 0x1A, 0xFC, 0xED, 0xB2, 0x3D, 0xC3, 0x11, 0xFC, 0x7B, 
  0xB7, 0xCA, 0x22, 0xFC, 0x43, 0xED, 0xB2, 0xDD, 0xE9
  }; 

const word  bootPhase2StrAddr = 0x0000; // Phase 2 payload image starting address
const byte  bootPhase2[] PROGMEM = {    // Phase 2 payload image (S121216 uBIOS + Basic)
  0xF3, 0xC3, 0xA4, 0x00, 0x00, 0x00, 0x00, 0x00, 0xC3, 0x91, 0x00, 0x00, 0x00, 0x00, 0x00, 0x00, 
  0xC3, 0x6A, 0x00, 0x00, 0x00, 0x00, 0x00, 0x00, 0xC3, 0x96, 0x00, 0x00, 0x00, 0x00, 0x00, 0x00, 
  0x00, 0x00, 0x00, 0x00, 0x00, 0x00, 0x00, 0x00, 0x00, 0x00, 0x00, 0x00, 0x00, 0x00, 0x00, 0x00, 
  0x00, 0x00, 0x00, 0x00, 0x00, 0x00, 0x00, 0x00, 0x18, 0x00, 0xF5, 0xE5, 0xDB, 0x01, 0xF5, 0x3A, 
  0x43, 0x20, 0xFE, 0x3F, 0x20, 0x03, 0xF1, 0x18, 0x1C, 0x2A, 0x3F, 0x20, 0x23, 0x7D, 0xFE, 0x3F, 
  0x20, 0x03, 0x21, 0x00, 0x20, 0x22, 0x3F, 0x20, 0xF1, 0x77, 0x3A, 0x43, 0x20, 0x3C, 0x32, 0x43, 
  0x20, 0xFE, 0x30, 0x38, 0x00, 0xE1, 0xF1, 0xFB, 0xED, 0x4D, 0x3A, 0x43, 0x20, 0xFE, 0x00, 0x28, 
  0xF9, 0xE5, 0x2A, 0x41, 0x20, 0x23, 0x7D, 0xFE, 0x3F, 0x20, 0x03, 0x21, 0x00, 0x20, 0xF3, 0x22, 
  0x41, 0x20, 0x3A, 0x43, 0x20, 0x3D, 0x32, 0x43, 0x20, 0xFE, 0x05, 0x30, 0x00, 0x7E, 0xFB, 0xE1, 
  0xC9, 0xF5, 0xF1, 0xD3, 0x01, 0xC9, 0x3A, 0x43, 0x20, 0xFE, 0x00, 0xC9, 0x7E, 0xB7, 0xC8, 0xCF, 
  0x23, 0x18, 0xF9, 0xC9, 0x21, 0xED, 0x20, 0xF9, 0x21, 0x00, 0x20, 0x22, 0x3F, 0x20, 0x22, 0x41, 
  0x20, 0xAF, 0x32, 0x43, 0x20, 0xED, 0x56, 0xFB, 0x21, 0xF1, 0x00, 0xCD, 0x9C, 0x00, 0x3A, 0x44, 
  0x20, 0xFE, 0x59, 0x20, 0x16, 0x21, 0x2A, 0x01, 0xCD, 0x9C, 0x00, 0xCD, 0x6A, 0x00, 0xE6, 0xDF, 
  0xFE, 0x43, 0x20, 0x0F, 0xCF, 0x3E, 0x0D, 0xCF, 0x3E, 0x0A, 0xCF, 0x3E, 0x59, 0x32, 0x44, 0x20, 
  0xC3, 0x50, 0x01, 0xFE, 0x57, 0x20, 0xE4, 0xCF, 0x3E, 0x0D, 0xCF, 0x3E, 0x0A, 0xCF, 0xC3, 0x53, 
  0x01, 0x75, 0x42, 0x49, 0x4F, 0x53, 0x20, 0x2D, 0x20, 0x53, 0x31, 0x32, 0x31, 0x32, 0x31, 0x36, 
  0x20, 0x28, 0x41, 0x64, 0x61, 0x70, 0x74, 0x65, 0x64, 0x20, 0x66, 0x72, 0x6F, 0x6D, 0x20, 0x5A, 
  0x38, 0x30, 0x20, 0x53, 0x42, 0x43, 0x20, 0x62, 0x79, 0x20, 0x47, 0x72, 0x61, 0x6E, 0x74, 0x20, 
  0x53, 0x65, 0x61, 0x72, 0x6C, 0x65, 0x29, 0x0D, 0x0A, 0x00, 0x0D, 0x0A, 0x75, 0x42, 0x49, 0x4F, 
  0x53, 0x3A, 0x20, 0x43, 0x6F, 0x6C, 0x64, 0x20, 0x6F, 0x72, 0x20, 0x77, 0x61, 0x72, 0x6D, 0x20, 
  0x73, 0x74, 0x61, 0x72, 0x74, 0x20, 0x28, 0x43, 0x2F, 0x57, 0x29, 0x3F, 0x00, 0x00, 0x00, 0x00, 
  0xC3, 0x56, 0x01, 0xC3, 0xF4, 0x01, 0xDD, 0x21, 0x00, 0x00, 0xC3, 0x61, 0x01, 0x07, 0x0A, 0x7D, 
  0x11, 0x21, 0x45, 0x20, 0xF9, 0xC3, 0x9C, 0x1D, 0x11, 0x2E, 0x04, 0x06, 0x63, 0x21, 0x45, 0x20, 
  0x1A, 0x77, 0x23, 0x13, 0x05, 0xC2, 0x70, 0x01, 0xF9, 0xCD, 0x2F, 0x06, 0xCD, 0xFD, 0x0B, 0x32, 
  0xEF, 0x20, 0x32, 0x3E, 0x21, 0x21, 0x43, 0x02, 0xCD, 0x9B, 0x12, 0xCD, 0x4C, 0x06, 0xCD, 0x55, 
  0x09, 0xB7, 0xC2, 0xAA, 0x01, 0x21, 0xA2, 0x21, 0x23, 0x7C, 0xB5, 0xCA, 0xBC, 0x01, 0x7E, 0x47, 
  0x2F, 0x77, 0xBE, 0x70, 0xCA, 0x98, 0x01, 0xC3, 0xBC, 0x01, 0xCD, 0x21, 0x0A, 0xB7, 0xC2, 0xFD, 
  0x04, 0xEB, 0x2B, 0x3E, 0xD9, 0x46, 0x77, 0xBE, 0x70, 0xC2, 0x85, 0x01, 0x2B, 0x11, 0xA1, 0x21, 
  0xCD, 0xC5, 0x07, 0xDA, 0x85, 0x01, 0x11, 0xCE, 0xFF, 0x22, 0xF4, 0x20, 0x19, 0x22, 0x9F, 0x20, 
  0xCD, 0x0A, 0x06, 0x2A, 0x9F, 0x20, 0x11, 0xEF, 0xFF, 0x19, 0x11, 0x3E, 0x21, 0x7D, 0x93, 0x6F, 
  0x7C, 0x9A, 0x67, 0xE5, 0x21, 0x0C, 0x02, 0xCD, 0x9B, 0x12, 0xE1, 0xCD, 0x3E, 0x19, 0x21, 0xFD, 
  0x01, 0xCD, 0x9B, 0x12, 0x31, 0xAB, 0x20, 0xCD, 0x2F, 0x06, 0xC3, 0x48, 0x05, 0x20, 0x42, 0x79, 
  0x74, 0x65, 0x73, 0x20, 0x66, 0x72, 0x65, 0x65, 0x0D, 0x0A, 0x00, 0x00, 0x5A, 0x38, 0x30, 0x20, 
  0x42, 0x41, 0x53, 0x49, 0x43, 0x20, 0x56, 0x65, 0x72, 0x20, 0x34, 0x2E, 0x37, 0x62, 0x0D, 0x0A, 
  0x43, 0x6F, 0x70, 0x79, 0x72, 0x69, 0x67, 0x68, 0x74, 0x20, 0x28, 0x43, 0x29, 0x20, 0x31, 0x39, 
  0x37, 0x38, 0x20, 0x62, 0x79, 0x20, 0x4D, 0x69, 0x63, 0x72, 0x6F, 0x73, 0x6F, 0x66, 0x74, 0x0D, 
  0x0A, 0x00, 0x00, 0x4D, 0x65, 0x6D, 0x6F, 0x72, 0x79, 0x20, 0x74, 0x6F, 0x70, 0x00, 0xB3, 0x17, 
  0x77, 0x18, 0xC9, 0x17, 0x48, 0x20, 0x5B, 0x11, 0xE0, 0x14, 0x89, 0x11, 0x3D, 0x1A, 0x1C, 0x1B, 
  0x58, 0x16, 0x8B, 0x1A, 0x91, 0x1B, 0x97, 0x1B, 0xF8, 0x1B, 0x0D, 0x1C, 0x34, 0x15, 0x78, 0x1C, 
  0x96, 0x20, 0x0D, 0x14, 0x25, 0x12, 0xA7, 0x14, 0x1C, 0x14, 0x2D, 0x14, 0x9A, 0x1C, 0x2D, 0x1D, 
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
  };

// ------------------------------------------------------------------------------
//
//  Global variables
//
// ------------------------------------------------------------------------------

byte              ioAddress;
byte              ioData;
byte              tempByte;
word              indexPhase2     =   0;      // Index for the bootPhase2[] array

// ------------------------------------------------------------------------------

void setup() {
  
// ------------------------------------------------------------------------------
//
//  Local variables
//
// ------------------------------------------------------------------------------

  byte  data;                                     // Data byte
  word  address;                                  // External RAM current address;

// ------------------------------------------------------------------------------

  // Initialize RESET_and BUSREQ_
  pinMode(RESET_, OUTPUT);                        // Configure RESET_ and set it ACTIVE
  digitalWrite(RESET_, LOW);

  pinMode(WAIT_RES_, OUTPUT);                     // Configure WAIT_RES_ and set it ACTIVE to reset the WAIT FF (U1C)
  digitalWrite(WAIT_RES_, LOW);

  pinMode(USER, OUTPUT);                          // USER led OFF
  digitalWrite(USER, HIGH);
  
  pinMode(INT_, INPUT_PULLUP);                    // Configure INT_ and set it NOT ACTIVE
  pinMode(INT_, OUTPUT);
  digitalWrite(INT_, HIGH);
  
  pinMode(BUSACK_, INPUT);                        // Configure BUSACK_ as input
  pinMode(WAIT_, INPUT);                          // Configure WAIT_ as input
  
  pinMode(BUSREQ_, INPUT_PULLUP);                 // Set BUSREQ_ HIGH
  pinMode(BUSREQ_, OUTPUT);
  digitalWrite(BUSREQ_, HIGH);
  
  DDRA = 0x00;                                    // Configure Z80 data bus D0-D7 (PA0-PA7) as input with pull-up
  PORTA = 0xFF;
  DDRC = DDRC & B00000011;                        // Configure Z80 address bus AD0-AD5 (PC2-PC7) as input with pull-up
  PORTC = PORTC | B11111100;
  DDRD = DDRD & B11100011;                        // Configure Z80 address bus AD6-AD8 (PD2-PD4) as input with pull-up
  PORTD = PORTD | B00011100;
  pinMode(MREQ_, INPUT_PULLUP);                   // Configure MREQ_ as input with pull-up
  pinMode(RD_, INPUT_PULLUP);                     // Configure RD_ as input with pull-up
  pinMode(WR_, INPUT_PULLUP);                     // Configure WR_ as input with pull-up
  
  // Initialize CLK @ 4MHz. Z80 clock_freq = (Atmega_clock) / (OCR2 + 1) = (Atmega_clock) / 2
  ASSR &= ~(1 << AS2);                            // Set Timer2 clock from system clock
  TCCR2 |= (1 << CS20);                           // Set Timer2 clock to "no prescaling"
  TCCR2 &= ~((1 << CS21) | (1 << CS22));
  TCCR2 |= (1 << WGM21);                          // Set Timer2 CTC mode
  TCCR2 &= ~(1 << WGM20);
  TCCR2 |= (1 <<  COM20);                         // Set "toggle OC2 on compare match"
  TCCR2 &= ~(1 << COM21);
  OCR2 = 0;                                       // Set the compare value to toggle OC2
  pinMode(CLK, OUTPUT);                           // Set OC2 as output and start to output the clock @ 4Mhz

  Serial.begin(9600);
  Serial.println();
  Serial.println("Z80-MBC (Mobile Breadboard Computer) - A041116");
  Serial.println("IOS - I/O Subsystem - S221116");
  Serial.println();
  
  delay(1);                                       // Wait for reset completed
  digitalWrite(WAIT_RES_, HIGH);                  // Set WAIT_RES_ HIGH
  digitalWrite(BUSREQ_, LOW);                     // Activate DMA request signal
  delay(1);
  digitalWrite(RESET_, HIGH);                     // Release Z80 from RESET
  delay(1);                                       // Wait for Z80 bus thee-stated

  // Load Phase 1 boot payload into external RAM with DMA and using address (AD0-AD8) and data (D0-D7) bus
  address = bootPhase1StrAddr;                    // Initialize the starting address of external RAM 
  Serial.println("IOS: Loading phase 1 boot program...");
  pinMode(WR_, OUTPUT);                           // Configure WR_ as ouput and set it HIGH
  digitalWrite(WR_, HIGH);
  pinMode(RD_, OUTPUT);                           // Configure RD_ as ouput and set it HIGH
  digitalWrite(RD_, HIGH);
  pinMode(MREQ_, OUTPUT);                         // Configure MREQ_ as ouput and set it HIGH
  digitalWrite(MREQ_, HIGH);
  for (int i = 0; i < sizeof(bootPhase1); i++)
  // Write boot program into external RAM
  {
    if (debugLev > 0)
    {
      Serial.print("DMA WRITE -> ADDR: ");
      Serial.print(address, HEX);
      Serial.print(" - DATA: ");
    }
    switch (i)
    // Get the current data to write into external RAM (Compliant with the S091116 specs)
    {
      case 3:
      // Send the LSB of the starting addres of the phase 2 boot program
        data = lowByte(bootPhase2StrAddr);
      break;
              
      case 4:
      // Send the MSB of the starting addres of the phase 2 boot program
        data = highByte(bootPhase2StrAddr);
      break;

      case 5:
      // Send the LSB of the lenght in bytes of the phase 2 boot program
        data = lowByte(sizeof(bootPhase2));
      break;

      case 6:
      // Send the MSB of the lenght in bytes of the phase 2 boot program
        data = highByte(sizeof(bootPhase2));
      break;

      default:
      // Get a byte of the phase 1 payload
        data = pgm_read_byte(&bootPhase1[i]);
      break;
    }

    if (debugLev > 0)
    {
      if (data < 0x10) Serial.print("0");
      Serial.println(data, HEX);
      Serial.println("      76543210       76543210");
      Serial.print("PORTC=");
      printBinaryByte(PORTC);
      Serial.print(" PORTD=");
      printBinaryByte(PORTD);
      Serial.println();
    }

    DDRA = 0xFF;                                  // Configure Z80 data bus D0-D7 (PA0-PA7) as output
    PORTA = data;                                 // Current output on data bus
    DDRC = DDRC | B11111100;                      // Configure Z80 address bus AD0-AD5 (PC2-PC7) as output
    DDRD = DDRD | B00011100;                      // Configure Z80 address bus AD6-AD8 (PD2-PD4) as output
    PORTC = (PORTC & B00000011) | ((lowByte(address) << 2) & B11111100);  // Output address AD0-AD5 (PC2-PC7)
    PORTD = (PORTD & B11100011) | (byte(address >> 4 ) & B00011100);      // Output address AD6-AD8 (PD2-PD4)
    //PORTC = (PORTC & B11111101) | ((highByte(address) & B00000100) >> 1); // Output address AD10 (PC1)
    digitalWrite(MREQ_, LOW);                     // Enable external RAM /CE1 pin
    digitalWrite(WR_, LOW);                       // Write data into current address of the external RAM (10us 1-0-1 pulse)
    digitalWrite(WR_, HIGH);
    address++;                                    // Set next address
  }
  Serial.println("IOS: Loading phase 1 done.");

  // Release Z80 address AD0-AD8 and data D0-D7 bus and run the Z80 CPU
  pinMode(WR_, INPUT_PULLUP);                     // Configure WR_ as input with pull-up
  pinMode(WR_, INPUT);
  pinMode(RD_, INPUT_PULLUP);                     // Configure RD_ as input with pull-up
  pinMode(RD_, INPUT);
  pinMode(MREQ_, INPUT_PULLUP);                   // Configure MREQ_ as input with pull-up
  DDRA = 0x00;                                    // Configure Z80 data bus D0-D7 (PA0-PA7) as input with pull-up
  PORTA = 0xFF;
  DDRC = DDRC & B00000011;                        // Configure Z80 address bus AD0-AD5 (PC2-PC7) as input with pull-up
  PORTC = PORTC | B11111100;
  DDRD = DDRD & B11100011;                        // Configure Z80 address bus AD6-AD8 (PD2-PD4) as input with pull-up
  PORTD = PORTD | B00011100;
  digitalWrite(RESET_, LOW);                      // Activate Z80 RESET_ signal
  digitalWrite(BUSREQ_, HIGH);                    // Release Z80 from DMA
  digitalWrite(RESET_, HIGH);                     // Release Z80 from RESET. Z80 is running from now.
  Serial.println("IOS: Z80 is running from now.");
  Serial.println();
}

// ------------------------------------------------------------------------------
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

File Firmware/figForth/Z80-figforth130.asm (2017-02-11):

	.TITLE	'8080 FIG-FORTH 1.3 VERSION 0  18JUL81'
;	FIG-FORTH  RELEASE 1.3  FOR THE 8080 PROCESSOR
;
;	ALL PUBLICATIONS OF THE FORTH INTEREST GROUP
;	ARE PUBLIC DOMAIN.  THEY MAY BE FURTHER
;	DISTRIBUTED BY THE INCLUSION OF THIS CREDIT
;	NOTICE:
;
;	THIS PUBLICATION HAS BEEN MADE AVAILABLE BY THE
;		     FORTH INTEREST GROUP
;		     P. O. BOX 1105
;		     SAN CARLOS, CA 94070
;
;	IMPLEMENTATION BY:	( 790528 )
;		JOHN CASSADY
;		339 15TH STREET
;		OAKLAND,CA 94612
;	MODIFIED BY:
;	   	KIM HARRIS
;               Bill McGee 30 Mar 83 for Apple ][
;	ACKNOWLEDGEMENTS:
;		GEORGE SHAW
;		TERRY HOLMES
;		MIKE PERRY
;		DON COLBURN
;		GEORGE FLAMMER
;		ROBT. D. VILLWOCK
;
	.PAGE
;
;----------------------------------------------------------
;
;	RELEASE & VERSION NUMBERS
;
FIGREL	.EQU	1	; FIG RELEASE #
FIGREV	.EQU	3	; FIG REVISION #
USRVER	.EQU	1	; USER VERSION #
;
;	ASCII CHARACTERS USED
;
ABL	.EQU	20H	; SPACE
ACR	.EQU	0DH	; CARRIAGE RETURN
ADOT	.EQU	02EH	; PERIOD
BELL	.EQU	07H	; (^G)
BSIN	.EQU	08H	; INPUT BACKSPACE
BSOUT	.EQU	08H	; OUTPUT BACKSPACE (^H)
DLE	.EQU	10H	; (^P)
LF	.EQU	0AH	; LINE FEED
FF	.EQU	0CH	; FORM FEED (^L)
;
;	MEMORY ALLOCATION
;
EM	.EQU	0A000H
NSCR	.EQU	4	; NUMBER OF 1024 BYTE SCREENS
KBBUF	.EQU	1024	; DATA BYTES PER DISK BUFFER
US	.EQU	40H	; USER VARIABLES SPACE
RTS	.EQU	0A0H	; RETURN STACK & TERM BUFF SPACE
;
CO	.EQU	KBBUF+4	; DISK BUFFER + 2 HEADER + 2 TAIL
NBUF	.EQU	NSCR*1024/KBBUF	; NUMBER OF BUFFERS
BUF1	.EQU	EM-CO*NBUF	; ADDR FIRST DISK BUFFER
INITR0	.EQU	BUF1-US		; (R0)
INITS0	.EQU	INITR0-RTS	; (S0)
;
	.PAGE
;
;-------------------------------------------------------
;
FALSE	.EQU	0
TRUE	.EQU	1
APPLE	.EQU	FALSE
HAVEDISK .EQU  FALSE
HAVECPM	.EQU FALSE
HAVE4CHIPZ80 .EQU TRUE
DEBUG .EQU FALSE

	.ORG	100H
; ENTRY FOR INITIAL EXECUTION AND COLD START
ORIG	NOP
	JMP	CLD	; VECTOR TO COLD START
; ENTRY FOR WARM START
	NOP
	JMP	WRM	; VECTOR TO WARM START
;
	.DB	FIGREL	; FIG RELEASE #
	.DB	FIGREV	; FIG REVISION #
	.DB	USRVER	; USER VERSION #
	.DB	0EH	; IMPLEMENTATION ATTRIBUTES
OFOR	.DW	FLAST	; TOPMOST WORD IN FORTH VOCABULARY
	.DW	BSIN	; BKSPACE CHARACTER
	.DW	INITR0	; INIT (UP)
;<<<<<< FOLLOWING USED BY COLD;
;	MUST BE IN SAME ORDER AS USER VARIABLES
OCLD0	.DW	INITS0	; INIT (S0)
	.DW	INITR0	; INIT (R0)
	.DW	INITS0	; INIT (TIB)
	.DW	31		; INIT (WIDTH)
	.DW	0		; INIT (WARNING)
	.DW	FLAST		; INIT (FENCE)
	.DW	INITDP		; INIT (DP)
	.DW	FORTH+6		; INIT (VOC-LINK)
OCLD1	.EQU	$
;<<<<<< END DATA USED BY COLD
	.DW	5H,0B320H	; CPU NAME	( HW,LW )
;				  ( 32 BIT, BASE 36 INTEGER )
OED	.DW	ELAST	; LAST EDITOR DEF.
;OASM	.DW	ALAST	; SAME FOR ASSEMBLER IF RESIDENT
;
;
;			+---------------+
;	B +ORIGIN	| . . .W:I.E.B.A|	IMPLEMENTATION
;			+---------------+	ATTRIBUTES
;			       ^ ^ ^ ^ ^
;			       | | | | +-- PROCESSOR ADDR =
;			       | | | |     { 0 BYTE | 1 WORD }
;			       | | | +---- HIGH BYTE AT
;			       | | |       { 0 LOW ADDR |
;			       | | |	     1 HIGH ADDR }
;			       | | +------ ADDR MUST BE EVEN
;			       | |	   { 0 YES | 1 NO }
;			       | +-------- INTERPRETER IS
;			       |	   { 0 PRE | 1 POST }
;			       |	   INCREMENTING
;			       +---------- { 0 ABOVE SUFFICIENT
;					     | 1 OTHER DIFFER-
;					     ENCES EXIST }
;
	.PAGE
;
;------------------------------------------------------
;
;	FORTH REGISTERS
;
;	FORTH	8080	FORTH PRESERVATION RULES
;	-----	----	------------------------
;	IP	BC	SHOULD BE PRESERVED ACROSS
;			  FORTH WORDS
;	W	DE	SOMETIMES OUTPUT FROM NEXT
;			MAY BE ALTERED BEFORE JMP'ING TO NEXT
;			INPUT ONLY WHEN 'DPUSH' CALLED
;	SP	SP	SHOULD BE USED ONLY AS DATA STACK
;			  ACROSS FORTH WORDS
;			MAY BE USED WITHIN FORTH WORDS
;			  IF RESTORED BEFORE 'NEXT'
;		HL	NEVER OUTPUT FROM NEXT
;			INPUT ONLY WHEN 'HPUSH' CALLED
;
UP	.DW	INITR0	; USER AREA POINTER
RPP	.DW	INITR0	; RETURN STACK POINTER
;
;------------------------------------------------------
;
;	COMMENT CONVENTIONS:
;
;	=	MEANS	"IS EQUAL TO"
;	<-	MEANS	ASSIGNMENT
;
;	NAME	=	ADDRESS OF NAME
;	(NAME)	=	CONTENTS AT NAME
;	((NAME))=	INDIRECT CONTENTS
;
;	CFA	=	ADDRESS OF CODE FIELD
;	LFA	=	ADDRESS OF LINK FIELD
;	NFA	=	ADDR OF START OF NAME FIELD
;	PFA	=	ADDR OF START OF PARAMETER FIELD
;
;	S1	=	ADDR OF 1ST WORD OF PARAMETER STACK
;	S2	=	ADDR OF 2ND WORD OF PARAMETER STACK
;	R1	=	ADDR OF 1ST WORD OF RETURN STACK
;	R2	=	ADDR OF 2ND WORD OF RETURN STACK
;	( ABOVE STACK POSITIONS VALID BEFORE & AFTER EXECUTION
;	OF ANY WORD, NOT DURING. )
;
;	LSB	=	LEAST SIGNIFICANT BIT
;	MSB	=	MOST SIGNIFICANT BIT
;	LB	=	LOW BYTE
;	HB	=	HIGH BYTE
;	LW	=	LOW WORD
;	HW	=	HIGH WORD
;	( MAY BE USED AS SUFFIX TO ABOVE NAMES )
;
	.PAGE
;
;---------------------------------------------------
;	DEBUG SUPPORT
;
;	TO USE:
;	(1)	SET 'BIP' TO IP VALUE TO HALT, CANNOT BE CFA
;	(2)	SET MONITOR'S BREAKPOINT PC TO 'BREAK'
;			OR PATCH 'HLT' INSTR. THERE
;	(3)	PATCH A 'JMP TNEXT' AT 'NEXT'
;	WHEN (IP) = (BIP) CPU WILL HALT
;
BIP	.DW	0	; BREAKPOINT ON IP VALUE
;
TNEXT	LXI	H,BIP
	MOV	A,M	; LB
	CMP	C
	JNZ	TNEXT1
	INX	H
	MOV	A,M	; HB
	CMP	B
	JNZ	TNEXT1
BREAK	NOP		; PLACE BREAKPOINT HERE
	NOP
	NOP
TNEXT1	LDAX	B
	INX	B
	MOV	L,A
	JMP	NEXT+3
;
;--------------------------------------------------
;
;	NEXT, THE FORTH ADDRESS INTERPRETER
;	  ( POST INCREMENTING VERSION )
;
trace:	.db 0
DPUSH	PUSH	D
HPUSH	PUSH	H
NEXT:	LDAX	B	;(W) <- ((IP))
	INX	B	;(IP) <- (IP)+2
	MOV	L,A
	LDAX	B
	INX	B
	MOV	H,A	; (HL) <- CFA
  .if DEBUG
	push PSW
	lda trace
	ora a
	jz notrace
	push H
	call PRINTI
	.db "NEXT:",0
	lhld RPP
	mvi A,INITR0 & 0FFH	;Inital RP
	sub L			; difference
	mov L,A
	mvi a,' '
trcilp:	jz trcilx		; Indent as per RPP "depth"
	out m32ser
	dcr L
	jnz trcilp
trcilx:	
	pop H
	push H
	call HEXHL
  .if 0
	mvi A,'.'
	out m32ser
	call HEXHL		;output RPP val
  .endif
	mvi A,'.'
	out m32ser
	lxi H,0
	dad SP
	call HEXHL
	mvi A, 13
	out m32ser
	mvi A, 10
	out m32ser
	pop H
notrace: pop PSW
  .endif
NEXT1:	MOV	E,M	;(PC) <- ((W))
	INX	H
	MOV	D,M
	XCHG
	PCHL		; NOTE: (DE) = CFA+1
;
	.PAGE
;
;		FORTH DICTIONARY
;
;
;	DICTIONARY FORMAT:
;
;				BYTE
;	ADDRESS	NAME		CONTENTS
;	------- ----		--------
;					  ( MSB=1
;					  ( P=PRECEDENCE BIT
;					  ( S=SMUDGE BIT
;	NFA	NAME FIELD	1PS<LEN>  < NAME LENGTH
;				0<1CHAR>  MSB=0, NAME'S 1ST CHAR
;				0<2CHAR>
;				  ...
;				1<LCHAR>  MSB=1, NAME'S LAST CHR
;	LFA	LINK FIELD	<LINKLB>  = PREVIOUS WORD'S NFA
;				<LINKHB>
;LABEL:	CFA	CODE FIELD	<CODELB>  = ADDR CPU CODE
;				<CODEHB>
;	PFA	PARAMETER	<1PARAM>  1ST PARAMETER BYTE
;		FIELD		<2PARAM>
;				  ...
;
;
DP0	.DB	83H	; LIT
	.DB	"LI"
	.DB	'T'+80H
	.DW	0	; (LFA)=0 MARKS END OF DICTIONARY
LIT	.DW	$+2	;(S1) <- ((IP))
	LDAX	B	; (HL) <- ((IP)) = LITERAL
	INX	B	; (IP) <- (IP) + 2
	MOV	L,A	; LB
	LDAX	B	; HB
	INX	B
	MOV	H,A
	JMP	HPUSH	; (S1) <- (HL)
 ;
	.DB	87H	; EXECUTE
	.DB	"EXECUT"
	.DB	'E'+80H
	.DW	LIT-6
EXEC	.DW	$+2
	POP	H	; (HL) <- (S1) = CFA
	JMP	NEXT1
;
	.DB	86H	; BRANCH
	.DB	"BRANC"
	.DB	'H'+80H
	.DW	EXEC-0AH
BRAN	.DW	$+2	;(IP) <- (IP) + ((IP))
BRAN1	MOV	H,B	; (HL) <- (IP)
	MOV	L,C
	MOV	E,M	; (DE) <- ((IP)) = BRANCH OFFSET
	INX	H
	MOV	D,M
	DCX	H
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

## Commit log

2017-01-31 First commit: 4chipZ80
    [ChipLabels.brd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]
2017-01-31 Add a pic to document V1 PCB errors and fixes.
2017-02-03 Add the .brd and .sch with mistakes that were made to work, so that people who wind up with such boards can refer to them.
    [Z80-4chip-PCBWAY-BAD.brd, Z80-4chip-PCBWAY-BAD.sch]
2017-02-04 Board/sch with bugs "fixed." Not yet fabbed or tested.
    [Z80-4chip7.brd, Z80-4chip7.sch]
2017-02-04 README for Gerbers-v1bad
2017-02-06 Change "RTS" to "DTR" on silkscreen
    [Z80-4chip7.brd]
2017-02-08 Move text to tPlace for more standard usage.
    [ChipLabels.brd]
2017-04-22 Mod silkscreen: RTS->DTR, add "Version 2." Generate Gerbers-V2.
    [Z80-4chip7.brd, Z80-4chip7.sch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]
2017-05-26 Modify Z80 brd to include power/gnd vias near prototype area. Add (untested) board designs for EEPROM floppy-emulation module.
    [EEPROM-protowiring.brd, EEPROM-protowiring.sch, EEPROM-smt.brd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]
2017-11-15 Add VCC/GND labels to bottom silk for new prototype-area vias. Bump version to V2.1 to account for the new power vias in prototype area. rename files to reflect version number (Z80-4chip-v2.1.*) Add 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
    [Z80-4chip-v2.1.brd, Z80-4chip-v2.1.sch]
2018-01-20 Initial commit of "version 3" This adds I2C EEPROM chips for CP/M compatibility. (but the prototyping area is decreased and part becomes just sea-of-pads.)
    [Z80-4chip-v3.brd, Z80-4chip-v3.sch]
2018-01-20 Slight adjustment to BSilk near EEPROMs; take Vcc labels off of vias.
    [Z80-4chip-v3.brd]
2018-01-20 oops; a bit of extra trash on bottom layer silkscreen.
    [Z80-4chip-v3.brd]
2018-01-20 Add directory and gerbv project for V3 Gerbers
2018-01-20 Move (and duplicate) the "version" text so it's not obscured by vias.
    [Z80-4chip-v3.brd]
2018-01-20 Add gerbers for v3
    [Z80-4chip-v3.GBL, Z80-4chip-v3.GBO, Z80-4chip-v3.GBS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]
